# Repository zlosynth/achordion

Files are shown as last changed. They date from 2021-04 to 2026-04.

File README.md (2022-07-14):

# Achordion

Chord-crafting quantizing wavetable oscillator module for Eurorack.

<p align="center">
   Panel illustration
</p>

* Wavetable synthesis, 37 wavetables, smooth transitions
* Up to 18 simultaneous voices
* Sub-octaves, duplicated tones, and chords
* 4 styles of playing - single tone, chords, arpeggios, intervals
* Quantization to selected scale
* Any scale can be played with the white piano keys
* Two lines with independent 1V/oct inputs and audio outputs
* LEDs visualizing dialed parameters
* Based around Electro-Smith's [Daisy Patch SM](https://www.electro-smith.com/daisy/patch-sm) platform
* Programmed in Rust

Find more details about the module, including a feature overview video and a
user manual, on its [website](https://zlosynth.com/achordion).

# Firmware

If you wish to upgrade to a newer version of firmware, refer to the respective
[Release description](https://github.com/zlosynth/achordion/releases).

# Development

See [DEVELOPMENT.md](DEVELOPMENT.md) to find some basic commands to interact
with the project. To learn more, read the code. A good place to start would be
[eurorack/src/main.rs](eurorack/src/main.rs).

# License

Software of Achordion is distributed under the terms of the General Public
License version 3. See [LICENSE-SOFTWARE](LICENSE-SOFTWARE) for details.

Schematics and PCB layout are distributed under the terms of Creative Commons
BY-SA. See [LICENSE-HARDWARE](LICENSE-HARDWARE) for details. Parts of the
schematics are based on [Emilie Gillet's Mutable
Instruments](https://github.com/pichenettes/eurorack), kudos to her for making
them open.

The manual is distributed under the terms of Creative Commons BY-SA too. See
[LICENSE-MANUAL](LICENSE-MANUAL) for details.

# Changelog

Read the [CHANGELOG.md](CHANGELOG.md) to learn about changes introduced in each
release.

# Versioning

See [VERSIONING.md](VERSIONING.md) to find detailed information about versioning
of the project and compatability between its software and hardware.

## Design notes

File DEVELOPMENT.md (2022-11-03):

# Development

## Rust version

The firmware of this project fits really tight into the flash of Daisy Patch SM.
With anything newer than Rust 1.63.0, it just won't fit. Before working with
this project, please make sure to install needed Rust toolchains:

``` sh
rustup toolchain install 1.63.0-x86_64-unknown-linux-gnu
rustup target add thumbv7em-none-eabihf --toolchain 1.63.0
cargo +1.63.0 install cargo-binutils
rustup +1.63.0 component add llvm-tools-preview
```

## Cheat sheet

Run formatting, linter and unit tests:

``` sh
make
```

Check firmware size:

``` sh
cargo size -- -m
cargo size -- -A
cargo bloat --release -n 50
```

Analyze the call stack:

``` sh
cargo +nightly call-stack --bin achordion-eurorack > cg.dot
dot -Tsvg cg.dot > cg.svg
firefox cg.svg
```

Flash using ST-Link:

``` sh
cd eurorack
openocd &
cargo run --release
```

Flash using DFU:

``` sh
make flash
```

Benchmark:

``` sh
cargo bench --bench bench
```

Profiling:

``` sh
rm -f target/release/deps/bench-*
rm -f callgrind.out.*
RUSTFLAGS="-g" cargo bench --bench bench --no-run
BENCH=$(find target/release/deps -type f -executable -name 'bench-*')
TEST=instrument
valgrind \
    --tool=callgrind \
    --dump-instr=yes \
    --collect-jumps=yes \
    --simulate-cache=yes \
    ${BENCH} --bench --profile-time 10 ${TEST}
kcachegrind callgrind.out.*
```

Build the manual. Find built PDFs under `manual/user` and `manual/build`:

``` sh
make manual
```

And more under `hack/` and in the `Makefile`.

## Gerbers, BOM and CPL

I extensivelly use https://github.com/Bouni/kicad-jlcpcb-tools to deal with the
matters listed in the title, and to prepare project for manufacture.

## Bandlimiting algorithm

Bandlimiting is available with two different filtering algorithms - fast fourier
transform (FFT) removing high frequency bins and state variable filter (SVF).
While FFT provides crips clean and very sharp sound, SVF goes little harder on
filtering and leaves slighly more muted, but warmer sound. Preferred algorithm
can be selected through a feature in `Cargo.toml` of both Eurorack and Pure Data
modules.

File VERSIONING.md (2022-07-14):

# Versioning

The project adheres to [Semantic Versioning](https://semver.org/), this applies
to both hardware and software, where the same version is used for both.

## Compatibility

Software remains backwards compatible with the hardware. Although some
functionality may be missing when an older version of the board is used, the
module will remain functional.

This also follows Semantic Versioning, e.g. board released under version v1.1.0
will work fine with software of v1.3.0. When compatibility is broken, the major
version will be bumped, e.g. when software requires a new button on the board,
the major version will be bumped from v1.1.0 to v2.0.0 and the software will not
work anymore with older releases of the board.

Finally, releases with major version 0 may break any time.

## Releasing

All substantial changes are recorded in the [CHANGELOG.md](CHANGELOG.md).

To release a new version of the module, versions in all `Cargo.toml` files, PCB
layout, schematic and silkscreen on the board must be adjusted. The Unreleased
section of the changelog must be renamed to the relevant version. New version of
manuals and firmware must be uploaded as artifacts to the GitHub release.

This process is automated through `./hack/release.sh <new_version>`.

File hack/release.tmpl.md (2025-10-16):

## Changes

${CHANGES}

## Firmware

Achordion's firmware can be upgraded to obtain new features and bug-fixes. To do so, download the binary from attachments bellow, navigate to [Electro-Smith's web programmer](https://flash.daisy.audio/) and follow the guide to upload the binary throught the "File Upload" tab.

## Input quantization

By default, the input CV snaps to the closest note voltage. This works well with normal inputs or tones that are already quantized to the scale.

If you use a keyboard for CV source, consider trying the alternative firmare `achordion-firmware-x.y.z-white-key-quantization.bin` which maps white keys to all notes of the scale.

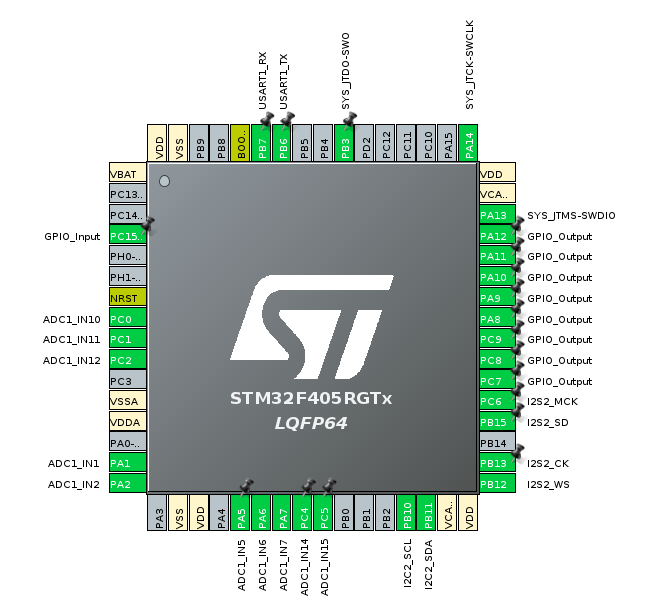
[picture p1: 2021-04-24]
eurorack/hardware/Screenshot from 2021-04-21 18-55-08.png

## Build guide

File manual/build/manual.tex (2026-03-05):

\documentclass[10pt,a4paper,twocolumn]{article}

\usepackage[T1]{fontenc} % extended font encoding
\usepackage{enumerate} % lists
\renewcommand{\familydefault}{\sfdefault} % sans-serif
\usepackage{microtype} % better text justification
\usepackage{graphicx} % allow including pictures
\usepackage{color} % colors for pictures
\usepackage{fancyhdr} % headers and footers
\usepackage{titling} % picture in the title
\usepackage{hyperref} % clickable links
\usepackage[left=2cm,right=2cm,top=3cm,bottom=3cm]{geometry} % wider and taller page

\pagenumbering{gobble} % hide page numbers
\setlength{\columnsep}{1cm} % space between columns
\setlength{\parskip}{\baselineskip} % paragraphs divided by empty lines
\setlength{\parindent}{0pt}

\pdfinfo{
   /Author (Zlosynth Instruments)
   /Title  (Achordion - Build Manual)
}

\pretitle{%
  \begin{center}
  \Huge
}
\posttitle{%
  \\
  \vspace{2cm}
  
  \end{center}
}

\begin{document}

\title{Achordion -- Build Manual}
\author{}
\date{}

\maketitle

\section{Overview}

You can always find the latest version of this build manual on \url{https://zlosynth.com/achordion-build-manual.pdf}.

This kit contains a printed circuit board (PCB) with all the surface mount device (SMD) parts already pre-soldered. The through-hole components are left to be assembled by you.

Pay attention to the orientation and position of all the parts. Desoldering them would be difficult and may break the module. Also, be careful not to touch the pre-soldered SMD parts with the soldering iron. Read through the whole manual first. Make sure you understand all the steps before you start soldering.

Electronic components are sensitive to static electricity. Before handling the PCB, ground yourself by touching a grounded metal object or use an anti-static wrist strap.

\newpage

\section{Tools required}

\begin{itemize}
  \item Soldering iron
  \item Masking tape
  \item Small flat head screwdriver
  \item Side-cutters
\end{itemize}

\newpage

\section{Bill of materials}

Start by unpacking all baggies into a bowl so you don't lose any components.

\begin{tabular}{@{}rl@{}}
  1 \texttimes & Front panel \\
  1 \texttimes & PCB (the black board) \\
  1 \texttimes & Daisy Patch Submodule (the yellow board) \\
  4 \texttimes & Potentiometer, M7 nut and washer \\
  1 \texttimes & Big knob \\
  3 \texttimes & Small knob \\
  7 \texttimes & 3.5mm jack socket, M6 nut and washer \\
  1 \texttimes & Tactile button \\
  8 \texttimes & Red LED \\
  1 \texttimes & Male connector 2\texttimes5 \\
  4 \texttimes & Female connector 2\texttimes5 \\
\end{tabular}

\begin{figure}[p]
  \centering
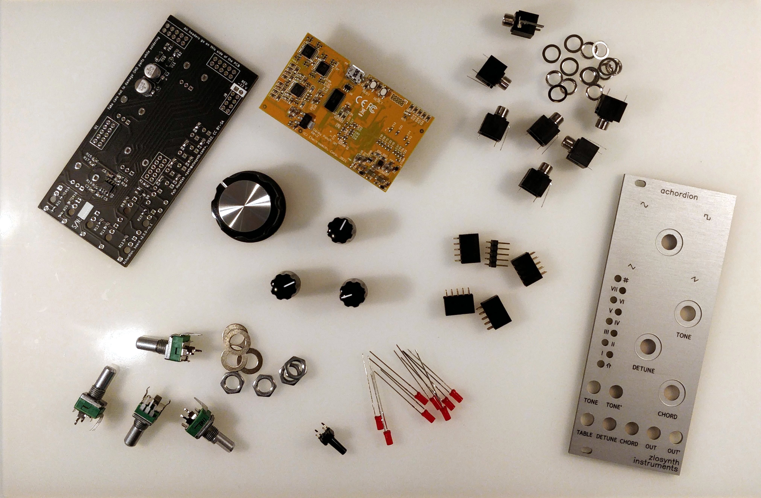
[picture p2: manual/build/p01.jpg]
  
  \caption{All the components laid out}
\end{figure}

\section{Daisy Patch Submodule}

The Daisy Patch Submodule is connected to the main PCB through a set of connectors.

\begin{enumerate}
  \item Mount the four female 2\texttimes5 connectors on the pins of the Daisy Patch Submodule. See figure \ref{daisy}. This will make it easier to align all the connectors properly.
  \item Plug the connectors of the submodule into the black PCB through footprints marked as ``SM''. Make sure to put them on the correct side of the PCB, where all four connectors are marked.
  \item Solder all the pins in.
  \item Once done, carefully detach Daisy Patch Submodule to prevent it from getting damaged while progressing with the build. It may be a little difficult. Pull each connector by a millimeter at a time.
\end{enumerate}

\begin{figure}[p]
  \centering
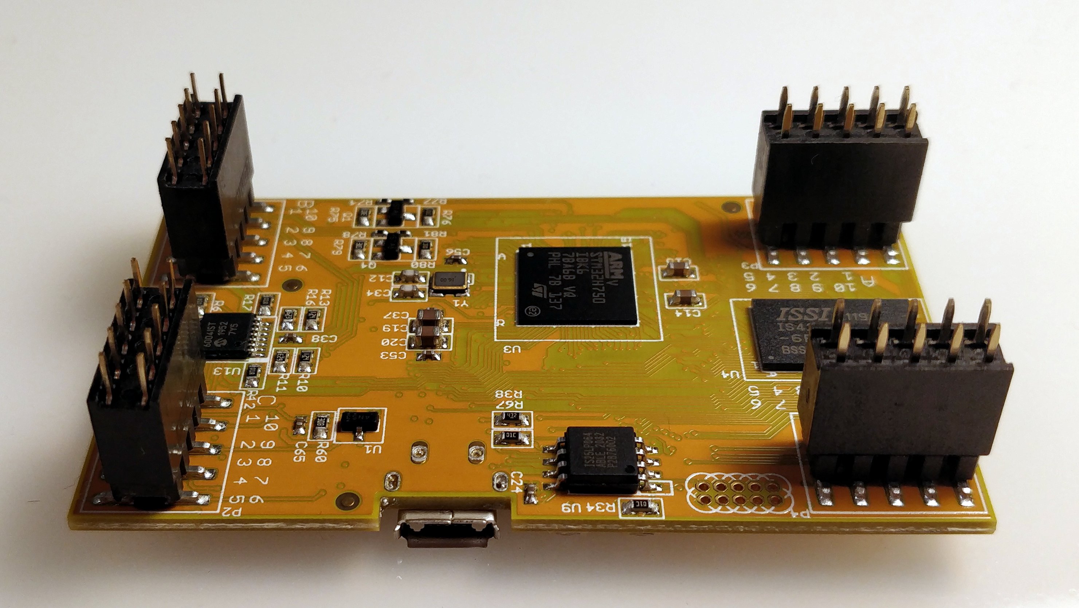
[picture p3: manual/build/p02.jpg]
  
  \caption{Connectors mounted on the submodule}
  \label{daisy}
\end{figure}

\section{Power}

The next step is to solder on the power connector.

\begin{enumerate}
  \item Take the male 2\texttimes5 connector and put the side with shorter legs through the footprint marked as ``Power''. Make sure to put it on the correct side of the PCB.
  \item Solder all the pins in. The result is illustrated in figure \ref{connectors}.
\end{enumerate}

\begin{figure}[p]
  \centering
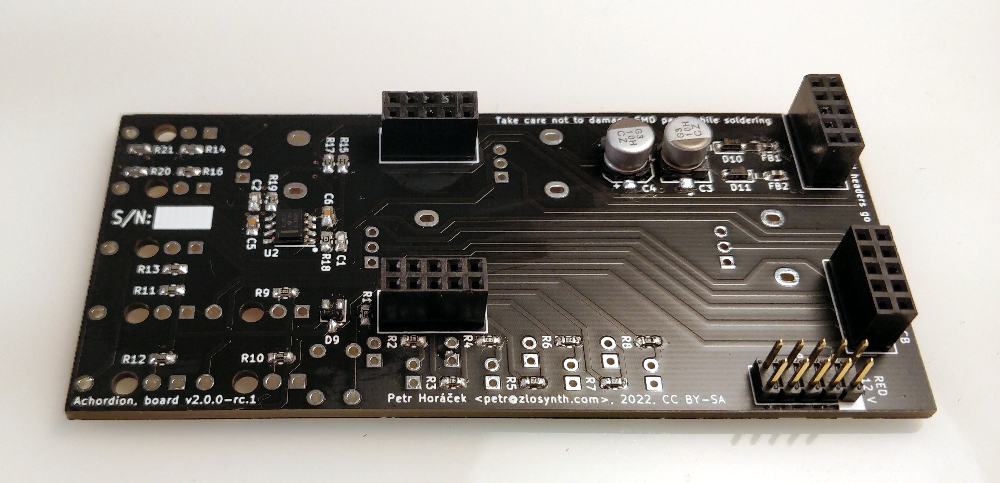
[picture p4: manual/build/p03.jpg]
  
  \caption{The power and submodule connectors}
  \label{connectors}
\end{figure}

\clearpage

\section{Front panel}

Now when all the internal parts are soldered, the next step would be to assemble parts sitting in the front panel.

\begin{enumerate}
  \item Snap in the button. Take care not to bend its leg. Don't push the button all the way to the PCB. See figure \ref{front components}.
  \item Place all potentiometers in the PCB. If the big legs are hard to snap in, flatten them with pliers first. Do not solder the legs yet.
  \item Put all jack sockets into the PCB.
  \item Put LEDs in place. The cathode (shorter leg) goes through the hole closer to the edge.
  \item Now when all parts are in, carefully put the front panel on them. Be patient aligning all parts so they fit through holes. The button may be a little problematic. If you see it not getting through, use tweezers to align its bottom part. Don't worry about the LEDs for now.
  \item Put washers on the pots and jacks. See figure \ref{washers}. Pot washers fit tightly into the panel, don't be afraid to push them in.
  \item Tighten all the potentiometers and jack sockets in place with their nuts. Take care not to scratch the panel. Plastic tools are prefered, and steel drivers should also serve well. If you only have pliers, put them in a thick plastic bag. Protect the panel!
  \item Solder in all the potentiometers and jacks.
  \item Use a masking tape on the portion of the panel with holes for LEDs, see figure \ref{masking}. Push the LEDs against the tape, even with the panel surface.
  \item Solder the LEDs. Then snap their legs off.
  \item Use tweezers to align the button. About 2 mm of the button should be sticking out of the panel. Test that the button can be easily clicked and returns to its resting position.
  \item Once the button is in a satisfying position, solder one of its legs, double-check it can be clicked and that it returns, and solder the remaining legs.
\end{enumerate}

\begin{figure}[p]
  \centering
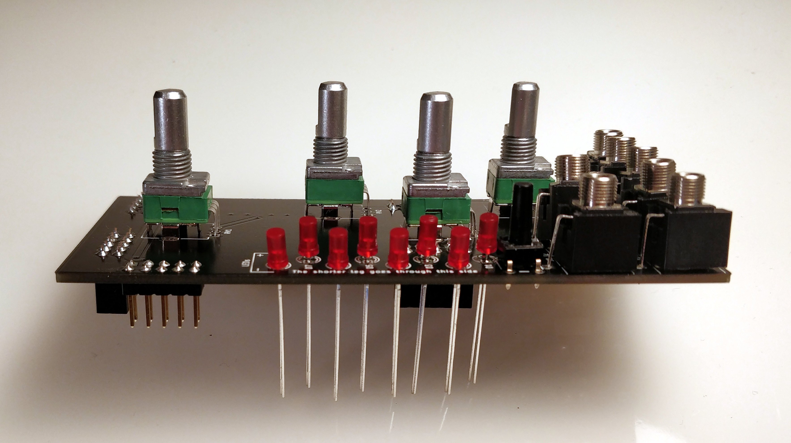
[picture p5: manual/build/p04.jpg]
  
  \caption{Side view with the front components in}
  \label{front components}
\end{figure}

\begin{figure}[p]
  \centering
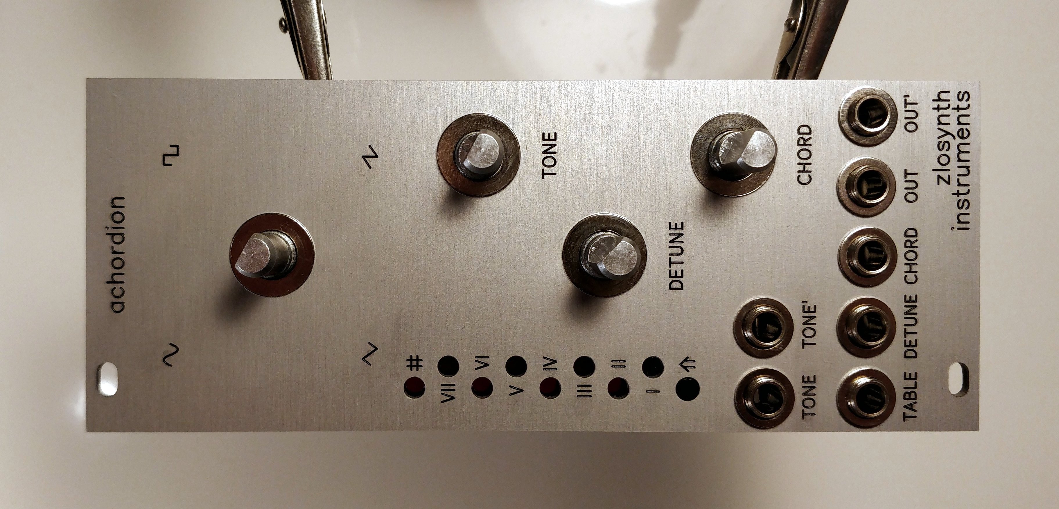
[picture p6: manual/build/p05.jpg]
  
  \caption{Pots and jacks with their washers on}
  \label{washers}
\end{figure}

\begin{figure}[p]
  \centering
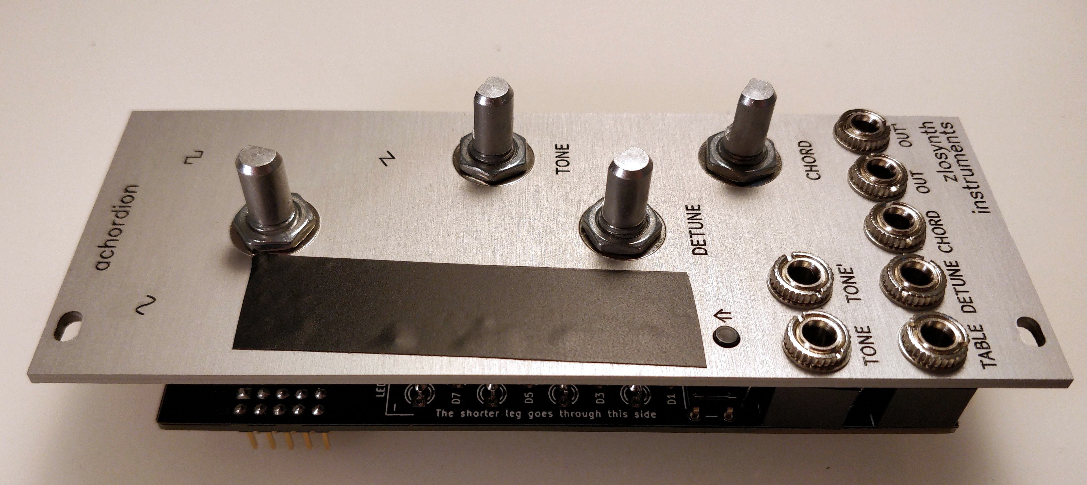
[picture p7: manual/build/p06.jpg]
  
  \caption{Taped LED holes}
  \label{masking}
\end{figure}

\clearpage

\section{Knobs}

You can now put knobs on the potentiometers.

\begin{enumerate}
  \item If the silver part of the big knob is protected with a sticky foil, peel it off.
  \item Put the big knob on the topmost potentiometer. Use a small flat screwdriver to tighten the screw of the pot. The screw should be pressing against the flat part of the shaft. Keep some distance between the knob and the panel.
  \item Put smaller black knobs on the remaining pots. Align them with the D-shaped shaft and press them in. You may need to pull them a little bit if you see they are scratching the nut.
\end{enumerate}

\begin{figure}[p]
  \centering
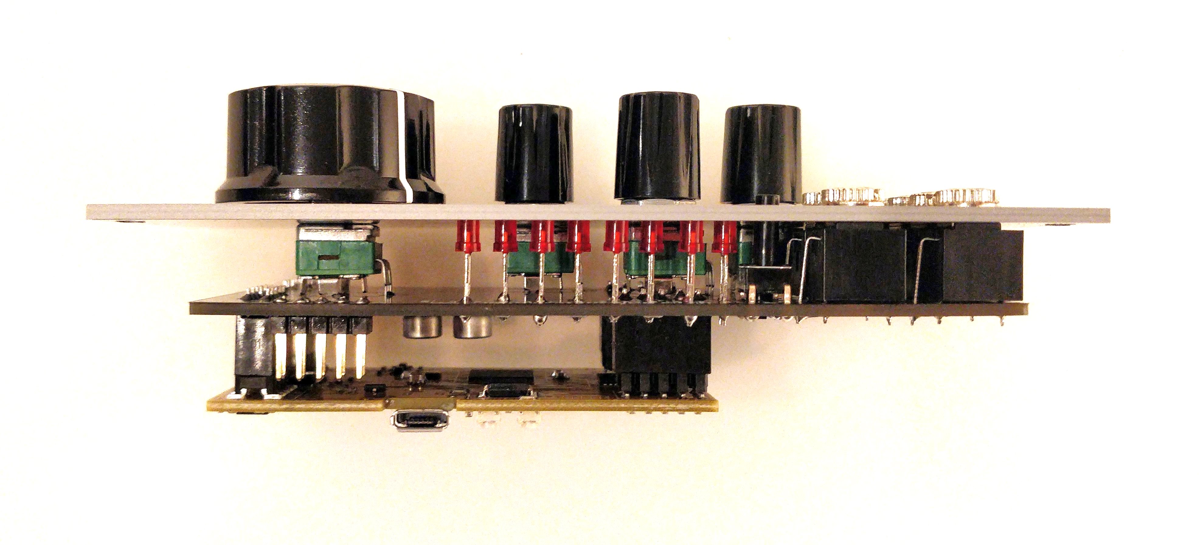
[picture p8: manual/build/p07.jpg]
  
  \caption{Side view of the assembled module}
\end{figure}

\section{Final assembly}

Connect the Daisy Patch Submodule to the main black PCB to complete the build.

\begin{figure}[p]
  \centering
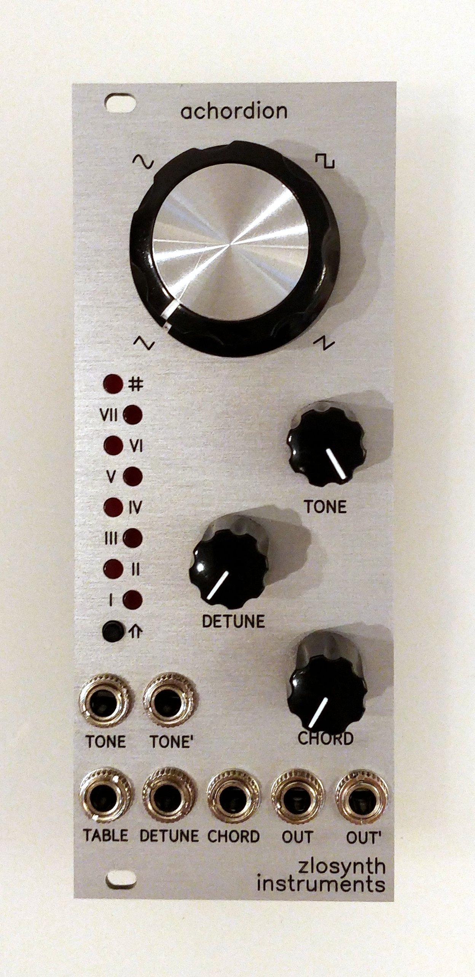
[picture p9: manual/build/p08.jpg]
  
  \caption{Front view of the assembled module}
\end{figure}

\section{Testing and inspection}

Before powering up the module, perform these checks to prevent damage:

\begin{itemize}
  \item Visually inspect all solder joints for missed connections, cold joints, and solder bridges.
  \item Always connect power with the system off. Verify the red stripe on the ribbon cable aligns with -12V on the PCB.
  \item If you can, test the module in an isolated case first to prevent damage to your entire Eurorack system if there are assembly errors.
\end{itemize}

\section{Congratulations}

The module is now complete. Have fun!

You can find the user manual on \url{https://zlosynth.com/achordion-user-manual.pdf}.

\end{document}

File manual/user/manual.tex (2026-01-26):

\documentclass[10pt,nofoldmark,nocombine]{leaflet} % digital leaflet format
% \documentclass[10pt,nofoldmark]{leaflet} % paper leaflet format

\usepackage[T1]{fontenc} % extended font encoding
\usepackage{enumerate} % lists
\renewcommand{\familydefault}{\sfdefault} % sans-serif
\usepackage{microtype} % better text justification
\usepackage{graphicx} % allow including pictures
\usepackage{color} % colors for pictures
\pagenumbering{gobble} % disable page numbering

\AddToBackground{1}{ % Background of a small page
  \put(0,0){\textcolor{black}{\rule{\paperwidth}{\paperheight}}}}

\newenvironment{packed_enumerate}{
\begin{enumerate}
  \setlength{\itemsep}{1pt}
  \setlength{\parskip}{0pt}
  \setlength{\parsep}{0pt}
}{\end{enumerate}}

\newenvironment{packed_enumerate_i}{
\begin{enumerate}[I]
  \setlength{\itemsep}{1pt}
  \setlength{\parskip}{0pt}
  \setlength{\parsep}{0pt}
}{\end{enumerate}}

\pdfinfo{
   /Author (Zlosynth Instruments)
   /Title  (Achordion - User Manual)
}

\begin{document}

\title{\textcolor{white}{MANUAL}}
\author{}
\date{}
\maketitle

\begin{center}
  
\end{center}

\newpage

\vspace{5mm}

Achordion allows you to do many things, but in essence, it is just a bunch of oscillators that never go out of tune or out of scale! Apart from playing anything between lush pads and hellish walls of sound, it enables you to easily jam with other musicians and explore characters of different scales. If you don't know any music theory, don't despair, the module will do all the harmony maths, and all left for you to do is to use your intuition. If you, on the other hand, do understand the basics of music theory, with this instrument, you can leverage it.

\section{Features}

This module is based on wavetable synthesis and contains a selection of 37 wavetables, offering smooth transitions between them. With up to 18 simultaneous voices, it allows enabling sub-octaves, duplicated tones or chords. Four modes of playing are available – single tone, selection of 18 standard chords (fifth, seventh and ninth), arpeggios, and intervals. All playing tones are quantized to a configurable scale. Two lines can be played at the same time, each controlled by an independent 1V/oct input. There are also two separate outputs, enabling to send each line to a different effect chain. Last but not least, a display consisting of 8 LEDs is used to make dialling of parameters easier.

\section{Installation}

Before installation, disconnect power from your case. While handling the module, avoid touching exposed components on the back of the PCB. Connect the power cable to your case power bus (2x5 connector on module side, 2x8 on bus side), ensuring the red stripe aligns with the -12V marking on both the module and power bus. Position the module on the rails and secure it with screws.

\section{Specs}

\begin{tabular}{@{}rl@{}}
  Width & 10 HP \\
  Depth & 28 mm \\
  Power & +12 V (85 mA), -12 V (7 mA) \\
  Input impedance & 100 kΩ \\
  CV inputs & 16-bit, 2 kHz \\
  Audio outputs & 24-bit, 48 kHz
\end{tabular}

\section{Controls, inputs and outputs}

On the left side, there is a column of LEDs (X) that visualize the currently selected parameter. The button below them (Y) accesses alternative parameters.

WAVETABLE (A) knob selects the wavetable. When the button is held down, this knob scrolls through banks.

TONE (B) knob selects the root note that should be playing. When the button is held down, this knob is used to select the scale's tonic.

DETUNE (C) knob controls the spread of secondary voices and the amount of detune. When the button is held down, this knob controls the scale mode.

CHORD (D) knob selects the chord or interval that should be playing. When the button is held down, this knob selects the mode in which chords are built.

CV inputs TONE (1) and TONE' (2) are used to control the root note playing on the main and the side line, respectively. When TONE is connected, the TONE knob controls octave offset. These inputs follow the 1V/oct standard, between -5 and +5 V.

CV inputs TABLE (3), DETUNE (4) and CHORD (5) control the same attributes as the knobs described above. The value set by the knob is added to the value set through the CV. All CV inputs span between -5 and +5~V.

Audio outputs OUT (6) and OUT' (7) play the main and the side line, respectively. When only one is connected, the outputs are mixed.

\section{Two Lines}

The module has two lines, the main line and the side line. The tone of these lines can be controlled independently while all the other attributes are shared.

The main line is controlled through the TONE knob and CV input. This line can play a chord, controlled through the CHORD knob and CV input.

The side line is controlled through the TONE' CV input and is playing only when a jack is connected. Unlike the main line, the side one is not playing chords.

\section{Wavetables}

There are 37 wavetables, divided into 4 banks:

\begin{packed_enumerate_i}
  \item Perfect -- classic waveforms: triangle, sine, square and saw. All of these are based on pure harmonics.
  \item Harsh -- full and distorted sounds. These can get very thick when played in rich chords.
  \item Soft -- cleaner sounds and bells.
  \item Sines -- the bottom half of this bank is a sequence of sine function multiplications that provide various sounds from clean to crazy noises. The upper half contains sums of sine functions. Sliding through them provides a low-pass filter effect.
\end{packed_enumerate_i}

The transitions between wavetables within a single bank are gradual and smooth, suitable for live modulation.

The bank can be selected by pressing the button while turning the WAVETABLE knob.

\section{Detune}

This parameter is set through the DETUNE knob and CV input. It controls the number of secondary voices per played note and their detune. The knob/CV input scrolls through four of these detune modes:

\begin{packed_enumerate_i}
  \item At first perfectly in tune, then moves each tone above or below its perfect pitch.
  \item The first factor of the chord is duplicated one octave lower. This is a classic sub-octave.
  \item Each tone in the chord is duplicated once with a unison. This produces a slight movement or vibrato effect, depending on the detune amount.
  \item Two sub-octaves per each factor. This can produce a very rich wall of sound and gets crazy with a lot of detune.
\end{packed_enumerate_i}

While moving through each mode, secondary voices are being gradually detuned. In lower detunes, the difference in frequency is very small and produces ``beats'' -- making the sound moving and warm. When it is pushed higher, it turns into a wild cacophony.

\section{Quantization}

To select the scale's root note, hold the button while turning the TONE knob. LEDs I through VII then symbolize notes of C major: C, D, ..., B. The \# LED signalizes that the note is sharp.

To select the scale's mode, hold the button while turning the DETUNE knob. LEDs I through VII then symbolize each of the modes. Selected mode affects the mood or character of the tune you are playing:

\begin{tabular}{@{}rl@{}@{}rl@{}}
  I & Ionian (major) \hspace{15mm} & V & Mixolydian  \\
  II & Dorian & VI & Aeolian (minor) \\
  III & Phrygian & VII & Locrian \\
  IV & Lydian & VIII & Harmonic minor \\
\end{tabular}

Quantization of TONE' can be switched off by tapping the DETUNE CV input with a jack while holding the button.

By default TONE and TONE' input CV snaps to the closest note. An alternative firmware can be installed to map white keyboard keys to the notes of any scale.

\section{Calibration}

While inputs TONE and TONE' follow the 1V/oct standard, they may not precisely match the connected CV source device. To calibrate each of these inputs, follow this procedure:

\begin{packed_enumerate}
  \item While holding the button, connect a jack to the input.
  \item The left column of LEDs should light up.
  \item Play note C on the CV source and press the button.
  \item Now, the right column of LEDs should light up.
  \item Play C one octave higher and press the button again.
\end{packed_enumerate}

\section{Chords}

This module allows playing chords of up to 5 factors, each affected by the detune.

To visualize selected chords, the LEDs display their factors. For example, if the selected chord is basic fifth, LEDs I, III and V light up to signalize that the first, third and fifth are playing. If this does not sound like anything to you, don't worry and just use your ears.

Furthermore, there are three different modes of playing chords. These can be accessed by holding the button while turning the CHORD knob:

\begin{packed_enumerate_i}
  \item Chords -- an assorted set of 19 chords. Starting with a single note, followed up with fifth, seventh, ninth and ninth inversions.
  \item Intervals -- not chords per se. In this mode, the root note is accompanied by another note of interval between minus two octaves to plus two octaves.
  \item Arpeggios -- four different chords that are incrementally built while the parameter is being increased. Starting with the root, adding second factor, third, ...
\end{packed_enumerate_i}

If the button is held while the chord CV is being plugged in, the input gets calibrated and can be then used in 1V/oct mode, with each chord assigned to a white key.

\section{Split Outputs}

There are two audio outputs in the module: OUT and OUT'. When only one of these outputs is connected, it gets mixed with the unconnected one. When both outputs are connected, each plays different voices. This allows to run through two different effect chains.

The content of these outputs depends on the playing lines. If the side line is playing, OUT plays the main line, controlled by TONE and OUT' is playing the side line, controlled by TONE'.

However, when the side line is not connected, OUT contains the root note of the main line, while OUT' contains the rest of the chord played by the main line.

\section{Reset}

Calibration settings and all secondary parameters (wavetable bank, scale tonic, scale mode, chord mode) are stored between restarts of the module. To reset their values, hold the button pressed while powering on the module.

\section{Configuration}

Some configuration options of the module can be adjusted:

\begin{packed_enumerate}
  \item Hold the button for 8 seconds.
  \item LEDs now signalize which options are enabled.
  \item Turn the WAVETABLE knob to adjust these options.
  \item Click the button to confirm the selection.
\end{packed_enumerate}

\begin{tabular}{@{}lll@{}}
  \textbf{LED} & \textbf{Option} \\
  VIII & \textit{reserved} \\
  VII  & \textit{reserved} \\
  VI   & \textit{reserved} \\
  V    & \textit{reserved} \\
  IV   & Tonic controlled by TONE' CV \\
  III  & Mode controlled by DETUNE CV \\
  II   & Modes ordered by brightness \\
  I    & Overdrive
\end{tabular}

\subsection{Tonic controlled by TONE' CV}

Scale's tonic can be controlled through the TONE' CV input, mapping to 1V/oct.

\subsection{Mode controlled by DETUNE CV}

Scale's mode can be controlled through the DETUNE CV input. The value set by the knob is added to the value set through the CV. The CV input spans between -5~and~+5~V.

\subsection{Modes ordered by brightness}

Modes can be reordered by their harmonic content, going from the brightest to the darkest.

\subsection{Overdrive}

Due to the headroom reserved for all 18 voices, default output levels are quite weak. To compensate for that, digital overdrive can be enabled. Note that this harms sound quality.

\section{Changelog}

\begin{tabular}{@{}rl@{}}
  v2.2 & The status LED blinks twice \\
       & Introduced configuration menu \\
       & Allow control of scale through CV \\
       & Add an option to order modes by brightness \\
       & Moved overdrive to the configuration menu \\
       & Added harmonic minor as the 8th mode \\
  v2.3 & The status LED blinks 3 times \\
       & First detune mode detunes all playing notes \\
  v2.4 & White key quantization was disabled \\
\end{tabular}

\section{Questions?}

\begin{center}
petr@zlosynth.com
\end{center}

\end{document}

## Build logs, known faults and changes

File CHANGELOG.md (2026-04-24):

# Changelog

All notable changes to this project will be documented in this file. See
[VERSIONING.md](VERSIONING.md) for more information about versioning and
backwards compatibility.

## Unreleased

* Use better footprints.
* Increase PCB edge clearance.

## 2.4.0

* Quantize TONE input 1V/oct CV to the closest note. The original white key
  quantization is now available as an alternative firmware.

## 2.3.0

* Introduce basic detune to the first detune section.
* Tune the output to match 440 Hz at A.
* Fix 1V/oct alignment of unquantized solo voice output.
* Pure Data externals were moved to a [dedicated project](https://github.com/zlosynth/automaton).
* Offer alternative firmware with white key quantization disabled.

## 2.2.1

* Split modal playing control to bind mode and scale CVs separately.
* Shift the range of TONE' by 2 octaves higher.
* Fix scaling of scale tonic CV to properly track 1V/oct.
* Persist tonic configuration between restarts.

## 2.2.0

* Blink the signal LED twice to signalize new version.
* Add harmonic minor mode.
* Introduce configuration menu.
* Allow remapping of CV inputs to control scale's tonic and mode.
* Enable overdrive through the configuration menu.
* Order of modes can be changed in the configuration menu.
* Extend the build manual with additional notes.
* Update pictures in the build manual to match version 2.

## 2.1.0

* Introduce togglable overdrive mode, compensating for big headroom.
* Add tooling holes to the PCB.
* Adjust V/oct response to reflect the new voltage range.
* Fix contents of each TONE output.

## 2.0.0

* Replace Daisy Seed with Daisy Patch Submodule, to assure CE requirements.
* Switch to 0805 footprints for easier hand-soldering.
* Change from 3 board to 2 board design to become skiff friendly.
* Remove debug pins due to lack of I/O.
* Prevent flash memory from getting worn out by utilizing its full range, saving
  only on change and increasing the backup interval.
* Blink the on-board LED every 2 seconds to indicate that the firmware is
  running.

## 1.3.1

* Fix english, change "unisono" to "unison".
* Disable line voice when its V/OCT input gets below zero.
* Fix a regression where the module would not fade in on boot.
* Document current requirements.

## 1.3.0

* Introduce documentation of the build process.
* Remove amplitude balancing on small chords. This causes weak signal output but
  guarantees stable loudness on continuous tones.
* Adjust solo and chord V/OCT tracking to react uniformly to input voltage.
* Avoid pops on chord changes by increasing the fade-in/out time of individual
  oscillators to 3 ms.

## 1.2.0

* Add mounting holes for distancing standoffs.
* Label boards and their sides to allow clear identification while building.
* Make it possible to disable quantization on the side line.
* Divide each octave V/OCT input to 7 almost equal sections.
* Document the depth of the module.
* Fully utilize the display while indicating the chord mode.
* Introduce V/OCT control of chords.
* Change CV range for chords to 0-10V.
* Improve the amplitude balance between low and high number of voices.
* Fix a bug where uninitialized voices would cause bit noise.
* Send solo output to SOLO' jack, as written in the documentation.
* Decrease the brightness of LEDs.

## 1.1.0

* The display now priorititizes what is being changed through pots over CV.
  Furthermore, one CV overtakes another only after the original source is idle.
* Fix calibration display. The lower octave is now signalized by LEDs on the
  left, higher on the right.
* Increase display sensitivity to CV, so it shows even small changes of input.
* If multiple CV inputs compete, the one that was controled through the pot most
  recently is picked.
* Prevent solo CV from bouncing between notes.
* Stabilize the display, so it does not blink while crossing large differences
  in V/OCT.
* Change the loading animation to go one LED at the time.
* Fix scale tonic control, so the pot does not wrap around when set to top.
* Resolve a bug where saved parameters sometimes failed to get restored.

## 1.0.0

* Convert PCB to two stacked layers for easier soldering.
* Change the panel layout.
* Expose debugging GPIO and UART pins.
* Wire compatibility version into the PCB.
* Document the module through a user manual.

## 0.16.0

* Allow using 3 voices in each chord degree.
* Use 2 sub-octave oscillators in the chord detune mode.
* Prevent phase lock by detuning solo if it collides with the chord.
* Prevent pop on change of detune by fading in/out the oscillators.
* Smoothly traverse wavetable changes between CV reconciles.
* Store bandlimited wavetables as f32 sequences to save on processing.
* Compensate amplitude of lower numbers of enabled oscillators.

## 0.15.0

* Speed up boot time of the module.
* Display progress of the boot on module's display.
* Exponentially fade in on boot.
* Increase the Note pot range to 6 octaves, extending in both directions.
* Make eurorack module louder.
* Replace vowel bank with sine multiple and sum sequences.
* Optimize booting code for size, to free up more space for wavetables.
* Make it possible to select between two bandlimiting algorithms.

## 0.14.0

* Introduce "style" setting to switch between different approaches to select
  harmonies. This also introduces alternative to chords where a simple interval
  +- 2 octaves is selected.
* Add a new play style which opens chords note by note. This could be used with
  ADSR connected to chord input to play more human-like.
* Add a new play mode which contains inversions of chords around the root.
* Increase the maximum number of chord degrees to 5 and populate the default
  chord style with some nineth chords.

## 0.13.0

* Add 4th voice to the instrument and allow its individual control through CV.
* List more accurate parts for the V/OCT CV input.
* Instead of pre-calculating bandlimited wavetables and storing them in flash,
  filter them during runtime initialization and store them in SRAM. This allows
  to fit more banks into eurorack and also to higher optimization.
* Reintroduce vowel wavetable bank into eurorack module.

## 0.12.0

* Align all quantization with white keys. All scales can be now played through
  white keys only, with black keys always quantizing to the previous white.
* Introduce CV calibration, allowing the V/OCT CV input to be calibrated
  precisely on any connected device.
* Allow reset of all stored parameters on boot by holding the button while
  powering on.
* Prevent jumps back and forth on borders between two discrete values of
  parameters.
* Scroll through notes via the pot lineary, instead of unequal jumps between
  tones and semitones.
* Increase detune phase on the display lineary.

## 0.11.0

* Remove CV buffering for faster response.
* Fixed a bug where settings backup to EEPROM was hogging the MCU and causing CV
  latency up to 100 ms. Now the CV latency should be around 2 ms.
* Increased control loop frequency to provide 0.5 ms latency.
* Simlified connected jack detection probe to reduce MCU usage.

## 0.10.0

* Update PCB with user labels for printing and easier soldering.
* Replace tantalum DC decoupling capacitors with aluminium.
* Use 10uF for DC decoupling capacitors.
* Scale modulation CV input range from -5 to +5 V.
* Scale V/OCT CV input range from 0 to +10 V.
* Add a script generating gerber and drill files.
* Add a script printing PDF with the schematic.
* Add a script printing PDF with assembly helper.
* Remove amplitude control.

## 0.9.0

* Remove component labels from the silkscreen.
* Add graphics to front and back of the PCB.
* Widen tracks on the PCB.
* Replace decoupling capacitor on DAC with LPF.
* Introduce ferrite beads to filter the power input.
* Major refactoring of the eurorack codebase, introducing new hardware
  abstractions.

## 0.8.1

* Fix dependency set on a daisy_bsp fork.

## 0.8.0

* Persist dialed settings between restarts.

## 0.7.0

* Visualize changes in settings on the display, both from pots and CV.
* Allow to offset Note CV to negative to compensate for high voltage input.
* Fix equilibrium of wavetables with depth of 16 bits.

## 0.6.0

* Added tooling supporting generation of wavetables from raw audio.
* Lowered LPF on wavetables to make the lower end thicker.
* Use floats for audio buffers instead of u16.
* Remove pulse wavetable bank.
* Add a bank compiled of FM, distorted and sampled wavetables.
* Add a bank compiled of soft wavetables.
* Add a bank of vocal wavetables.

## 0.5.0

* Allow control of wavetable bank through Wavetable pot while holding the
  button.
* Allow control of scale root through Note pot while holding the button. This
  value will be combined with the Tonic CV in case it is connected.
* Allow control of scale mode through Chord pot while holding the button. This
  value will be combined with the Mode CV in case it is connected.
* Remove support for 4 degrees of chords. It draws too much resources.

## 0.4.0

* Allowed control of all parameters through CV:
  - Root note, adhering to V/OCT. When connected, Note potentiometer controls
    octave offset.
  - Wavetable position. When connected, Wavetable potentiometer controls the
    offset.
  - Chord. When connected, Chord potentiometer controls the offset.
  - Detune. When connected, Detune potentiometer controls the offset.
  - Scale mode.
  - Scale root note, adhering to V/OCT.
* Fixed the bug where root and chord went to both channels.
* Introduced fade in when the module is powered on.
* Fixed an issue where full detune setting would disable detune.

## 0.3.0

* Detune sections now respond logarithmically, this allows for finer control in
  lower values.
* Added pulse waveforms of variable width.
* Support multiple wavetable banks.
* Label button and probe pins on the PCB.
* Switch to Daisy Seed, STM32H7.

## 0.2.0

* Finally starting using Semantic Versioning.
* Compensate perceived amplitudes, making sure that combination of less
  oscillators sound as loud as many.
* Added support for silenced chord degrees, allowing for subset of voices to
  sound and build smaller chords/intervals.
* Added support for chord degrees spanning multiple upwards octaves.
* Added support for inverted chords.
* Added support for seventh chords.
* Defined versioning and compatibility policies.

## 7123cbb, revision 3

* Increased size of pads on the PCB for easier hand soldering.

## 27707a5, revision 2

* Converted the board into 2-layer design.
* Replacing 7-segment display with LEDs.
* Added CV probing to the PCB, allowing to detect connected jacks.
* Mixing both output channels when only one jack is plugged in.
* Added labels to PCB silkscreen.
* Spaced out jack sockets on the PCB.
* Adjusted all the CV ranges.
* Introduced Pure Data External to allow for easier testing.
* Quantizing note to diatonic scale.
* Wavetable control.
* Chord control.
* Removed control over MIDI.
* Added detune control and suboscillators.
* Improved reading of potentiometer values with buffering.

## cb3808f, revision 1

* Introduced panel sketch.
* PCB designed based around Daisy Seed.
* 4 basic waveforms.
* Quantizing notes to selected scale.
* Chord, scale mode, and tone controlled via MIDI over USB.

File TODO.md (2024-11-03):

# TODO

- [ ] Make even quantization of input the default. Note in the docs that if white key quantization is not tracking accurately, alternative firmware is available.
- [ ] Switch to bootloader, to allow bigger firmware size. Adapt the build scripts, update the DEVEL and release note guides.
- [ ] Switch to the scale library of Arplus.
- [ ] Implement controlled mode, with scales being set by Arplus.

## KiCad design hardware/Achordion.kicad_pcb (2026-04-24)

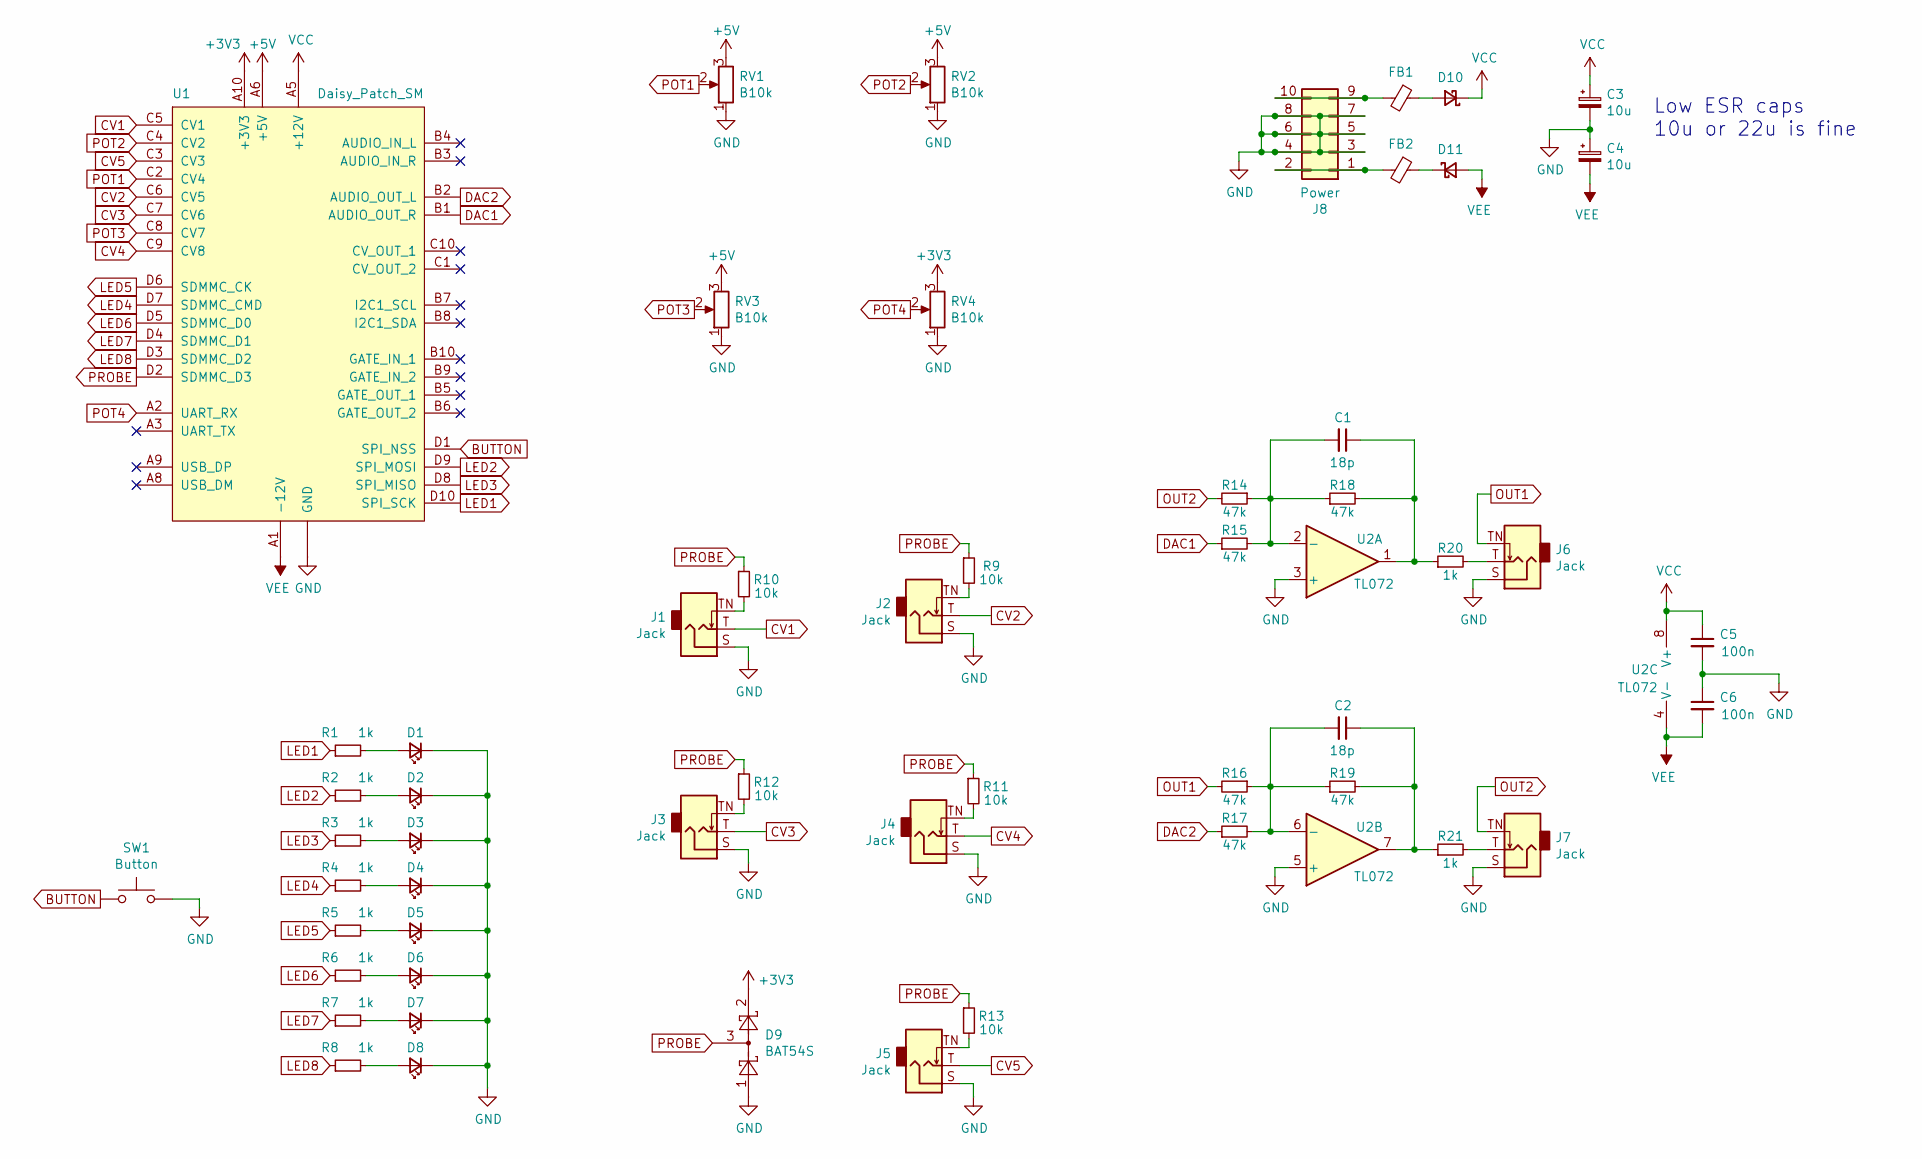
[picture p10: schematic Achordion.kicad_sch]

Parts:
C1, C2: 18p; C_0805_2012Metric_Pad1.18x1.45mm_HandSolder; Mfr Part Number CL10C180JB81PNC; LCSC C1647
C3, C4: 10u; CP_Elec_5x5.8; Mfr Part Number T491B226M016AT; LCSC C122226
C5, C6: 100n; C_0805_2012Metric_Pad1.18x1.45mm_HandSolder; Mfr Part Number CL10F104ZO8NNNC; LCSC C14663
D1, D2, D3, D4, D5, D6, D7, D8: LED; LED_D3.0mm; Mfr Part Number WP710A10SRD/D
D9: BAT54S; SOT-23_Handsoldering; Mfr Part Number BAT54S,215
D10, D11: Schottky; D_SOD-123; Mfr Part Number STPS0540ZY; LCSC C8598
FB1, FB2: FB; L_0805_2012Metric_Pad1.05x1.20mm_HandSolder
J1, J2, J3, J4, J5, J6, J7: Jack; Jack_3.5mm_QingPu_WQP-PJ398SM_Vertical_CircularHoles
J8: Power; Power_Connector_Connfly; Mfr Part Number 87914-1016
R1, R2, R3, R4, R5, R6, R7, R8: 1k; R_0805_2012Metric_Pad1.20x1.40mm_HandSolder; Mfr Part Number CR0603-FX-3650ELF; LCSC C23032
R9, R10, R11, R12, R13: 10k; R_0805_2012Metric_Pad1.20x1.40mm_HandSolder; Mfr Part Number CR0603-FX-1002ELF; LCSC C25744
R14, R16, R18, R19: 47k; R_0805_2012Metric_Pad1.20x1.40mm_HandSolder; Mfr Part Number CR0603-FX-4702ELF; LCSC C25819
R15, R17: 47k; R_0805_2012Metric_Pad1.20x1.40mm_HandSolder; Mfr Part Number CR0603-JW-682ELF; LCSC C23212
R20, R21: 1k; R_0805_2012Metric_Pad1.20x1.40mm_HandSolder; Mfr Part Number CR0603-FX-1001ELF; LCSC C21190
RV1, RV2, RV3, RV4: B10k; Potentiometer_Alpha; Mfr Part Number RK09L1140A66
SW1: Button; SW_PUSH_6mm; Mfr Part Number SKHHDTA010
U1: Daisy_Patch_SM
U2: TL072; SOIC-8_3.9x4.9mm_P1.27mm; Mfr Part Number TL072CD; LCSC C163525

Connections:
+3V3: D9.2, RV4.3, U1.A10 (+3V3)
+5V: RV1.3, RV2.3, RV3.3, U1.A6 (+5V)
BUTTON: SW1.1, U1.D1 (SPI_NSS)
CV1: J1.T, U1.C5 (CV1)
CV2: J2.T, U1.C6 (CV5)
CV3: J3.T, U1.C7 (CV6)
CV4: J4.T, U1.C9 (CV8)
CV5: J5.T, U1.C3 (CV3)
DAC1: R15.1, U1.B1 (AUDIO_OUT_R)
DAC2: R17.1, U1.B2 (AUDIO_OUT_L)
GND: C3.2, C4.1, C5.2, C6.1, D1.1 (K), D2.1 (K), D3.1 (K), D4.1 (K), D5.1 (K), D6.1 (K), D7.1 (K), D8.1 (K), D9.1, J1.S, J2.S, J3.S, J4.S, J5.S, J6.S, J7.S, J8.3, J8.4, J8.5, J8.6, J8.7, J8.8, RV1.1, RV2.1, RV3.1, RV4.1, SW1.2, U1.A4 (GND), U1.A7 (GND), U2.3 (+), U2.5 (+)
LED1: R1.1, U1.D10 (SPI_SCK)
LED2: R2.1, U1.D9 (SPI_MOSI)
LED3: R3.1, U1.D8 (SPI_MISO)
LED4: R4.1, U1.D7 (SDMMC_CMD)
LED5: R5.1, U1.D6 (SDMMC_CK)
LED6: R6.1, U1.D5 (SDMMC_D0)
LED7: R7.1, U1.D4 (SDMMC_D1)
LED8: R8.1, U1.D3 (SDMMC_D2)
unnamed: C1.1, R18.2, R20.1, U2.1
unnamed: C2.1, R19.2, R21.1, U2.7
unnamed: D1.2 (A), R1.2
unnamed: D2.2 (A), R2.2
unnamed: D3.2 (A), R3.2
unnamed: D4.2 (A), R4.2
unnamed: D5.2 (A), R5.2
unnamed: D6.2 (A), R6.2
unnamed: D7.2 (A), R7.2
unnamed: D8.2 (A), R8.2
unnamed: D10.2 (A), FB1.1
unnamed: D11.1 (K), FB2.1
unnamed: J1.TN, R10.2
unnamed: J2.TN, R9.2
unnamed: J3.TN, R12.2
unnamed: J4.TN, R11.2
unnamed: J5.TN, R13.2
unnamed: J6.T, R20.2
unnamed: J7.T, R21.2
unnamed: FB2.2, J8.1, J8.2
unnamed: FB1.2, J8.9, J8.10
unnamed: C1.2, R14.1, R15.2, R18.1, U2.2 (-)
unnamed: C2.2, R16.1, R17.2, R19.1, U2.6 (-)
OUT1: J6.TN, R16.2
OUT2: J7.TN, R14.2
POT1: RV1.2, U1.C2 (CV4)
POT2: RV2.2, U1.C4 (CV2)
POT3: RV3.2, U1.C8 (CV7)
POT4: RV4.2, U1.A2 (UART_RX)
PROBE: D9.3, R9.1, R10.1, R11.1, R12.1, R13.1, U1.D2 (SDMMC_D3)
VCC: C3.1, C5.1, D10.1 (K), U1.A5 (+12V), U2.8 (V+)
VEE: C4.2, C6.2, D11.2 (A), U1.A1 (-12V), U2.4 (V-)

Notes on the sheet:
Low ESR caps 10u or 22u is fine

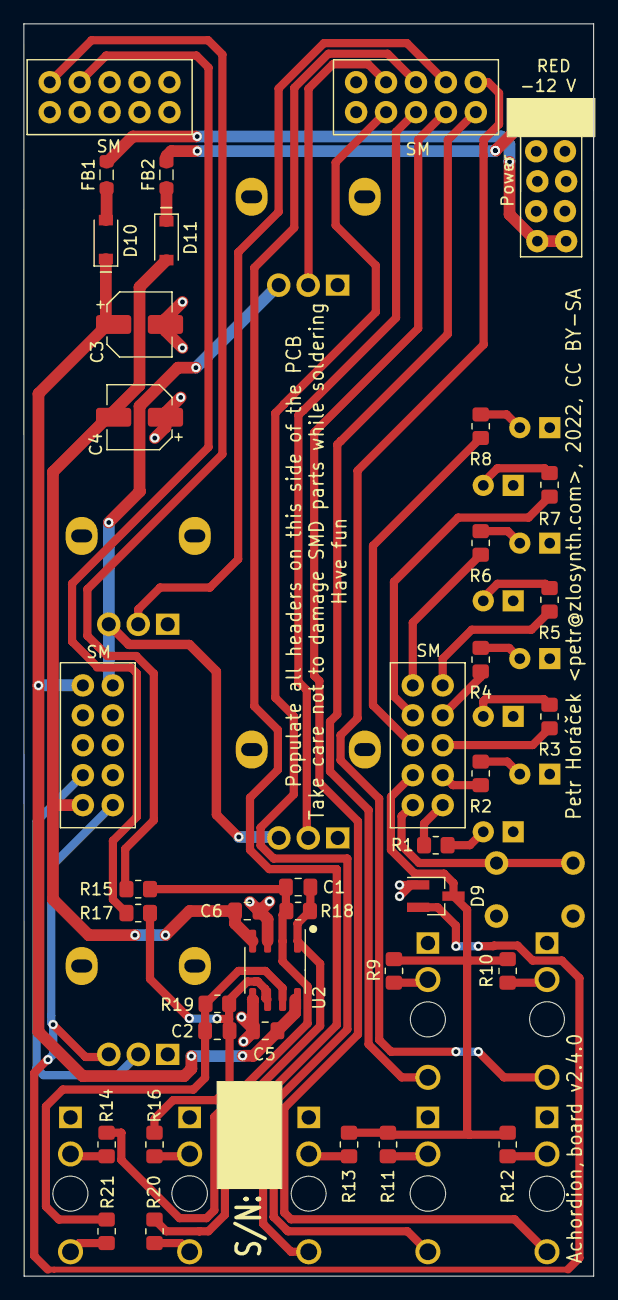
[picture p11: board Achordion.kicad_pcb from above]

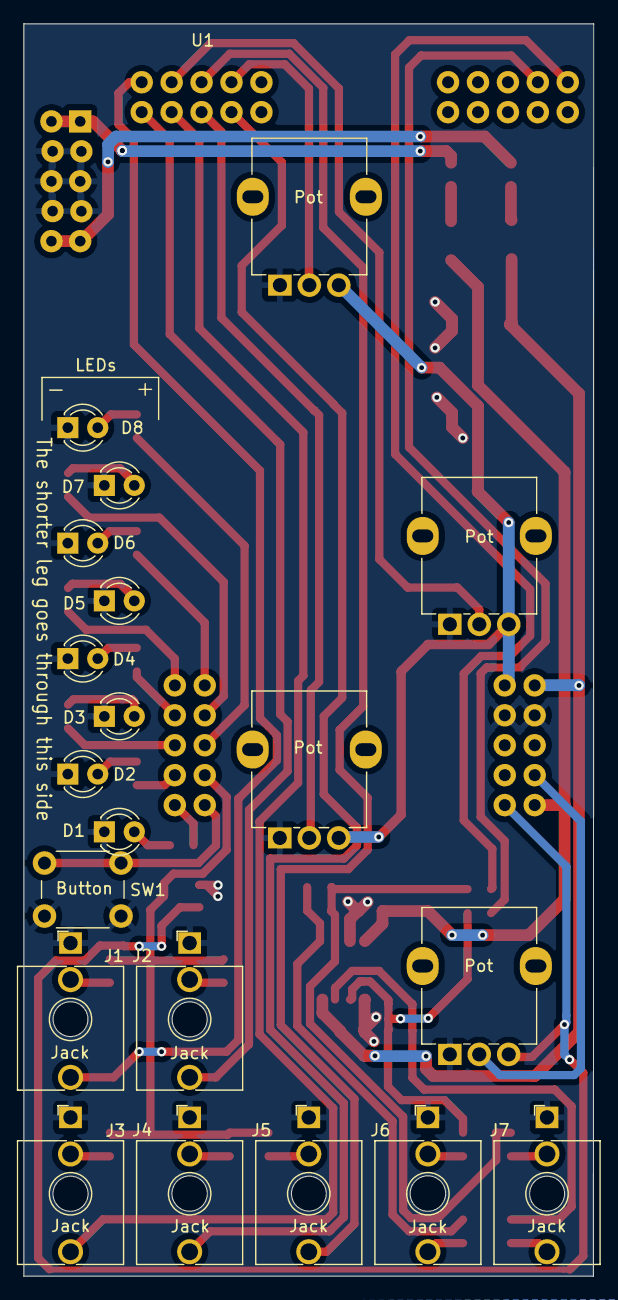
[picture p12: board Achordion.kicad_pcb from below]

Board: 2 copper layers, 48.4 x 106.3 mm, 55 parts (21 on the bottom side), 51 nets.

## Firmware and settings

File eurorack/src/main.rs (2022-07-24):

#![no_std]
#![no_main]
#![allow(unknown_lints)]
#![allow(clippy::inconsistent_struct_constructor)]
#![allow(clippy::new_without_default)]
#![allow(clippy::manual_map)]

mod bank;
mod controls;
mod display;
mod input_activity;
mod storage;
mod system;

#[macro_use]
mod profiling;

use panic_halt as _;

#[allow(unused_imports)]
use micromath::F32Ext;

use rtic::app;
use rtic::cyccnt::Instant;
use rtic::cyccnt::U32Ext as _;

use achordion_lib::display::{self as display_lib, Action as DisplayAction, CalibrationPhase};
use achordion_lib::instrument::Instrument;
use achordion_lib::store::Parameters;

use crate::bank::WAVETABLE_BANKS;
use crate::controls::{Controls, ControlsConfig};
use crate::display::{Display, DisplayConfig};
use crate::input_activity::InputActivity;
use crate::storage::Storage;
use crate::system::audio::{Audio, BLOCK_LENGTH, SAMPLE_RATE};
use crate::system::led_user::{Led, LedUser};
use crate::system::System;

pub const SECOND: u32 = 480_000_000;
const CV_PERIOD: u32 = SECOND / 2000;

const BLINKS: u8 = 2;

const BACKUP_COUNTDOWN_LENGTH: u8 = 60;
const BACKUP_COUNTDOWN_SLEEP: u32 = SECOND;

#[app(device = stm32h7xx_hal::pac, peripherals = true, monotonic = rtic::cyccnt::CYCCNT)]
const APP: () = {
    struct Resources {
        controls: Controls,
        display: Display,
        storage: Storage,
        led_user: LedUser,
        input_activity: InputActivity,
        audio: Audio,
        instrument: Option<Instrument<'static>>,
        lastly_stored_parameters: Parameters,
    }

    /// Initialize all the peripherals.
    #[init(spawn = [initialize])]
    fn init(cx: init::Context) -> init::LateResources {
        let system = System::init(cx.core, cx.device);

        let mut storage = Storage::new(system.flash);

        let parameters = if system.button.active_no_filter() {
            let parameters = Parameters::default();
            while system.button.active_no_filter() {}
            parameters
        } else {
            storage.load_parameters()
        };

        let controls = Controls::new(
            ControlsConfig {
                adc1: system.adc1,
                adc2: system.adc2,
                alt_button: system.button,
                pot_wavetable: system.pots.pot1,
                pot_note: system.pots.pot2,
                pot_detune: system.pots.pot3,
                pot_chord: system.pots.pot4,
                cv_voct: system.cvs.cv1,
                cv_solo: system.cvs.cv2,
                cv_wavetable: system.cvs.cv3,
                cv_detune: system.cvs.cv4,
                cv_chord: system.cvs.cv5,
                cv_probe: system.cvs.cv_probe,
            },
            parameters,
        );

        let display = Display::new(DisplayConfig {
            led1: system.leds.led1,
            led2: system.leds.led2,
            led3: system.leds.led3,
            led4: system.leds.led4,
            led5: system.leds.led5,
            led6: system.leds.led6,
            led7: system.leds.led7,
            led_sharp: system.leds.led8,
        });

        let mut audio = system.audio;
        audio.spawn();

        cx.spawn.initialize().unwrap();

        init::LateResources {
            controls,
            display,
            audio,
            storage,
            led_user: system.led_user,
            instrument: None,
            input_activity: InputActivity::new(),
            lastly_stored_parameters: parameters,
        }
    }

    #[task(schedule = [fade_in, reconcile_controls], spawn = [backup_countdown, blink], resources = [display, instrument], priority = 2)]
    fn initialize(mut cx: initialize::Context) {
        let display = cx.resources.display;
        bank::setup(display);

        let mut instrument = Instrument::new(
            unsafe { &WAVETABLE_BANKS.as_ref().unwrap()[..] },
            SAMPLE_RATE,
        );
        instrument.set_amplitude(0.0);

        cx.resources
            .instrument
            .lock(|resource| *resource = Some(instrument));

        cx.schedule
            .reconcile_controls(Instant::now() + CV_PERIOD.cycles())
            .unwrap();
        cx.schedule
            .fade_in(Instant::now() + (SECOND / 10).cycles())
            .unwrap();
        cx.spawn.backup_countdown(BACKUP_COUNTDOWN_LENGTH).unwrap();
        cx.spawn.blink(true, BLINKS).unwrap();
    }

    #[task(binds = DMA1_STR1, priority = 3, resources = [audio, instrument])]
    fn dsp(cx: dsp::Context) {
        let audio = cx.resources.audio;

        let mut buffer_solo = [0.0; BLOCK_LENGTH];
        let mut buffer_chord = [0.0; BLOCK_LENGTH];

        if let Some(instrument) = cx.resources.instrument {
            instrument.populate(&mut buffer_solo, &mut buffer_chord);
        }

        audio.update_buffer(|buffer| {
            buffer.iter_mut().enumerate().for_each(|(i, x)| {
                *x = (buffer_chord[i], buffer_solo[i]);
            })
        });
    }

    #[task(schedule = [fade_in], resources = [instrument], priority = 2)]
    fn fade_in(mut cx: fade_in::Context) {
        let mut amplitude = 0.0;

        cx.resources.instrument.lock(|instrument| {
            let instrument = instrument.as_mut().unwrap();
            amplitude = if instrument.amplitude() < 0.00005 {
                0.0001
            } else {
                instrument.amplitude() * 1.1
            };
            instrument.set_amplitude(amplitude.min(1.0));
        });

        if amplitude < 1.0 {
            cx.schedule
                .fade_in(Instant::now() + 6_000_000.cycles())
                .unwrap();
        }
    }

    #[task(schedule = [reconcile_controls], resources = [controls, display, instrument, input_activity], priority = 2)]
    fn reconcile_controls(mut cx: reconcile_controls::Context) {
        let activity = cx.resources.input_activity;
        let controls = cx.resources.controls;
        let display = cx.resources.display;

        controls.update();

        let mut calibration_action = None;
        let mut configuration_action = None;
        let mut any_actions = None;
        let mut pot_actions = None;
        let mut chord_degrees = None;

        cx.resources.instrument.lock(|instrument| {
            let instrument = instrument.as_mut().unwrap();
            calibration_action = Some(reconcile_calibration(controls));
            configuration_action = Some(reconcile_configuration(controls));
            any_actions = Some(reconcile_all_changes(controls, instrument));
            pot_actions = Some(reconcile_pot_activity(controls, instrument));
            chord_degrees = Some(instrument.chord_degrees());
        });

        if let Some(display_action) = activity.reconcile(
            calibration_action.unwrap(),
            configuration_action.unwrap(),
            pot_actions.unwrap(),
            any_actions.unwrap(),
            DisplayAction::SetChord(chord_degrees.unwrap()),
        ) {
            display.set(display_lib::reduce(display_action));
        };

        cx.schedule
            .reconcile_controls(Instant::now() + CV_PERIOD.cycles())
            .unwrap();
    }

    #[task(schedule = [backup_countdown], spawn = [backup_collector], priority = 2)]
    fn backup_countdown(cx: backup_countdown::Context, countdown: u8) {
        fn launch_backup_collector(cx: backup_countdown::Context) {
            cx.spawn.backup_collector().ok().unwrap();
        }

        fn tick_countdown(cx: backup_countdown::Context, countdown: u8) {
            cx.schedule
                .backup_countdown(Instant::now() + BACKUP_COUNTDOWN_SLEEP.cycles(), countdown)
                .unwrap();
        }

        if countdown > 1 {
            tick_countdown(cx, countdown - 1);
        } else {
            launch_backup_collector(cx);
        }
    }

    #[task(spawn = [backup_executor], resources = [controls], priority = 2)]
    fn backup_collector(cx: backup_collector::Context) {
        fn launch_backup_executor(cx: backup_collector::Context, parameters: Parameters) {
            cx.spawn.backup_executor(parameters).ok().unwrap();
        }

        let parameters = cx.resources.controls.parameters();
        launch_backup_executor(cx, parameters);
    }

    #[task(schedule = [backup_countdown], resources = [storage, lastly_stored_parameters])]
    fn backup_executor(mut cx: backup_executor::Context, parameters: Parameters) {
        fn start_countdown(cx: backup_executor::Context) {
            cx.schedule
                .backup_countdown(
                    Instant::now() + BACKUP_COUNTDOWN_SLEEP.cycles(),
                    BACKUP_COUNTDOWN_LENGTH,
                )
                .unwrap();
        }

        let lastly_stored_parameters = &mut cx.resources.lastly_stored_parameters;

        if parameters.close_to(lastly_stored_parameters) {
            start_countdown(cx);
        } else {
            **lastly_stored_parameters = parameters;

            let storage = &mut cx.resources.storage;
            storage.save_parameters(parameters);

            start_countdown(cx);
        }
    }

    #[task(schedule = [blink], resources = [led_user])]
    fn blink(cx: blink::Context, on: bool, blinks: u8) {
        const TIME_ON: u32 = SECOND / 5;
        const TIME_OFF_SHORT: u32 = SECOND / 5;
        const TIME_OFF_LONG: u32 = 2 * SECOND;

        if on {
            cx.resources.led_user.on();
            cx.schedule
                .blink(Instant::now() + TIME_ON.cycles(), false, blinks)
                .unwrap();
        } else {
            cx.resources.led_user.off();
            if blinks > 1 {
                cx.schedule
                    .blink(Instant::now() + TIME_OFF_SHORT.cycles(), true, blinks - 1)
                    .unwrap();
            } else {
                cx.schedule
                    .blink(Instant::now() + TIME_OFF_LONG.cycles(), true, BLINKS)
                    .unwrap();
            }
        }
    }

    extern "C" {
        fn EXTI0();
        fn EXTI1();
    }
};

fn reconcile_calibration(controls: &mut Controls) -> Option<DisplayAction> {
    if controls.calibration_waiting_low() {
        Some(DisplayAction::SetCalibration(CalibrationPhase::WaitingLow))
    } else if controls.calibration_waiting_high() {
        Some(DisplayAction::SetCalibration(CalibrationPhase::WaitingHigh))
    } else if controls.calibration_succeeded() {
        Some(DisplayAction::SetCalibration(CalibrationPhase::Succeeded))
    } else if controls.calibration_failed() {
        Some(DisplayAction::SetCalibration(CalibrationPhase::Failed))
    } else {
        None
    }
}

fn reconcile_configuration(controls: &mut Controls) -> Option<DisplayAction> {
    if controls.config_open() {
        Some(DisplayAction::SetConfiguration(controls.config().into()))
    } else {
        None
    }
}

fn reconcile_all_changes(
    controls: &mut Controls,
    instrument: &mut Instrument,
) -> [Option<DisplayAction>; 9] {
    let new_chord_root_degree = if controls.note_from_pot() {
        instrument.set_chord_root_linear(controls.note())
    } else {
        instrument.set_chord_root_voct(controls.note())
    };
    let chord_root_action = if let Some(new_chord_root_degree) = new_chord_root_degree {
        Some(DisplayAction::SetChordRootDegree(new_chord_root_degree))
    } else {
        None
    };

    let new_degrees = instrument.set_chord_degrees(controls.chord());
    let degrees_action = if let Some(new_degrees) = new_degrees {
        Some(DisplayAction::SetChord(new_degrees))
    } else {
        None
    };

    instrument.set_chord_quantization(controls.chord_quantization());

    let new_solo = instrument.set_solo_voct(controls.solo());
    let solo_action = if let Some(new_solo) = new_solo {
        Some(DisplayAction::SetSolo(new_solo))
    } else {
        None
    };

    instrument.set_solo_quantization(controls.solo_quantization());

    let new_scale_root = instrument.set_scale_root_voct(controls.scale_root());
    let scale_root_action = if let Some(new_scale_root) = new_scale_root {
        Some(DisplayAction::SetScaleRoot(new_scale_root))
    } else {
        None
    };

    let new_scale_mode = instrument.set_scale_mode(
        controls.scale_mode(),
        controls.modes_ordered_by_brightness(),
    );
    let scale_mode_action = if let Some(new_scale_mode) = new_scale_mode {
        Some(DisplayAction::SetScaleMode(new_scale_mode))
    } else {
        None
    };

    let new_wavetable_bank = instrument.set_wavetable_bank(controls.wavetable_bank());
    let wavetable_bank_action = if let Some(new_wavetable_bank) = new_wavetable_bank {
        Some(DisplayAction::SetWavetableBank(new_wavetable_bank))
    } else {
        None
    };

    let new_wavetable = instrument.set_wavetable(controls.wavetable());
    let wavetable_action = if let Some(new_wavetable) = new_wavetable {
        Some(DisplayAction::SetWavetable(new_wavetable))
    } else {
        None
    };

    let new_style = instrument.set_style(controls.style());
    let style_action = if let Some(new_style) = new_style {
        Some(DisplayAction::SetStyle(new_style))
    } else {
        None
    };

    let new_detune = instrument.set_detune(controls.detune());
    let detune_action = if let Some((new_detune_index, new_detune_phase)) = new_detune {
        Some(DisplayAction::SetDetune(new_detune_index, new_detune_phase))
    } else {
        None
    };

    instrument.set_overdrive(controls.overdrive());

    [
        chord_root_action,
        degrees_action,
        solo_action,
        scale_root_action,
        scale_mode_action,
        wavetable_bank_action,
        wavetable_action,
        style_action,
        detune_action,
    ]
}

fn reconcile_pot_activity(
    controls: &mut Controls,
    instrument: &mut Instrument,
) -> [Option<DisplayAction>; 8] {
    let chord_action = if controls.chord_pot_active() {
        let chord_degrees = instrument.chord_degrees();
        Some(DisplayAction::SetChord(chord_degrees))
    } else {
        None
    };

    let wavetable_bank_action = if controls.wavetable_bank_pot_active() {
        let wavetable_bank = instrument.wavetable_bank();
        Some(DisplayAction::SetWavetableBank(wavetable_bank))
    } else {
        None
    };

    let note_action = if controls.note_pot_active() {
        let chord_root_degree = instrument.chord_root_degree();
        Some(DisplayAction::SetChordRootDegree(chord_root_degree))
    } else {
        None
    };

    let scale_root_action = if controls.scale_root_pot_active() {
        let scale_root = instrument.scale_root();
        Some(DisplayAction::SetScaleRoot(scale_root))
    } else {
        None
    };

    let scale_mode_action = if controls.scale_mode_pot_active() {
        let scale_mode = instrument.scale_mode();
        Some(DisplayAction::SetScaleMode(scale_mode))
    } else {
        None
    };

    let wavetable_action = if controls.wavetable_pot_active() {
        let wavetable = instrument.wavetable();
        Some(DisplayAction::SetWavetable(wavetable))
    } else {
        None
    };

    let style_action = if controls.style_pot_active() {
        let style = instrument.style();
        Some(DisplayAction::SetStyle(style))
    } else {
        None
    };

    let detune_action = if controls.detune_pot_active() {
        let (detune_index, detune_phase) = instrument.detune();
        Some(DisplayAction::SetDetune(detune_index, detune_phase))
    } else {
        None
    };

    [
        chord_action,
        wavetable_bank_action,
        note_action,
        scale_root_action,
        scale_mode_action,
        wavetable_action,
        style_action,
        detune_action,
    ]
}

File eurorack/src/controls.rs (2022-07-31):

#[allow(unused_imports)]
use micromath::F32Ext;

use daisy::hal;

use hal::adc::{Adc, Enabled};
use hal::pac::{ADC1, ADC2};

use achordion_lib::config::Config;
use achordion_lib::store::Parameters;

use crate::system::Button;
use crate::system::Probe;
use crate::system::{Cv1, Cv2, Cv3, Cv4, Cv5};
use crate::system::{Pot1, Pot2, Pot3, Pot4};

// V/OCT CV spans from -5.0 to 5.0 V.
const VOCT_CV_RANGE: f32 = 10.0;

pub struct ControlsConfig {
    pub adc1: Adc<ADC1, Enabled>,
    pub adc2: Adc<ADC2, Enabled>,
    pub alt_button: Button,
    pub pot_wavetable: Pot1,
    pub pot_note: Pot2,
    pub pot_detune: Pot3,
    pub pot_chord: Pot4,
    pub cv_voct: Cv1,
    pub cv_solo: Cv2,
    pub cv_wavetable: Cv3,
    pub cv_detune: Cv4,
    pub cv_chord: Cv5,
    pub cv_probe: Probe,
}

pub struct Controls {
    adc1: Adc<ADC1, Enabled>,
    adc2: Adc<ADC2, Enabled>,
    button: Button,
    pot1: Pot1,
    pot2: Pot2,
    pot3: Pot3,
    pot4: Pot4,
    cv1: Cv1,
    cv2: Cv2,
    cv3: Cv3,
    cv4: Cv4,
    cv5: Cv5,
    probe: Probe,

    parameters: Parameters,

    last_note_pot_reading: f32,
    last_wavetable_pot_reading: f32,
    last_chord_pot_reading: f32,
    last_detune_pot_reading: f32,

    note_source: NoteSource,

    calibration_target: CalibrationTarget,
    calibration_state: CalibrationState,

    configuration_state: ConfigurationState,
}

#[derive(Clone, Copy)]
enum CalibrationTarget {
    Cv1,
    Cv2,
    Cv5,
    None,
}

#[derive(Clone, Copy)]
enum CalibrationState {
    Inactive,
    Entering,
    CalibratingLow,
    CalibratingHigh(f32),
    Succeeded,
    Failed,
}

#[derive(Clone, Copy)]
enum ConfigurationState {
    Inactive,
    Active,
}

#[derive(Clone, Copy)]
enum Submenu {
    None,
    Calibration,
    Configuration,
}

impl Submenu {
    pub fn is_none(&self) -> bool {
        matches!(self, Self::None)
    }

    pub fn is_calibration(&self) -> bool {
        matches!(self, Self::Calibration)
    }

    pub fn is_configuration(&self) -> bool {
        matches!(self, Self::Configuration)
    }
}

#[derive(Clone, Copy)]
enum NoteSource {
    Cv,
    Pot,
}

impl Controls {
    pub fn new(config: ControlsConfig, parameters: Parameters) -> Self {
        let mut controls = Self {
            adc1: config.adc1,
            adc2: config.adc2,
            button: config.alt_button,
            pot1: config.pot_wavetable,
            pot2: config.pot_note,
            pot3: config.pot_detune,
            pot4: config.pot_chord,
            cv1: config.cv_voct,
            cv2: config.cv_solo,
            cv3: config.cv_wavetable,
            cv4: config.cv_detune,
            cv5: config.cv_chord,
            probe: config.cv_probe,

            parameters,

            // These values are used to cache the last read value while the pot
            // is in its alternative mode (depending on the button state).
            last_note_pot_reading: 0.0,
            last_wavetable_pot_reading: 0.0,
            last_chord_pot_reading: 0.0,
            last_detune_pot_reading: 0.0,

            note_source: NoteSource::Pot,

            calibration_target: CalibrationTarget::None,
            calibration_state: CalibrationState::Inactive,

            configuration_state: ConfigurationState::Inactive,
        };

        // Initial probe tick, so the signal has enough time to propagate to all
        // the detectors.
        controls.probe.tick();

        controls
    }

    pub fn parameters(&self) -> Parameters {
        self.parameters
    }

    pub fn note(&self) -> Option<f32> {
        if self.parameters.note < 0.5 / 12.0 {
            None
        } else {
            Some(self.parameters.note)
        }
    }

    pub fn solo(&self) -> Option<f32> {
        if self.parameters.solo_enabled {
            Some(self.parameters.solo)
        } else {
            None
        }
    }

    pub fn note_from_pot(&self) -> bool {
        matches!(self.note_source, NoteSource::Pot)
    }

    pub fn wavetable(&self) -> f32 {
        self.parameters.wavetable
    }

    pub fn chord(&self) -> f32 {
        self.parameters.chord
    }

    pub fn style(&self) -> f32 {
        self.parameters.style
    }

    pub fn detune(&self) -> f32 {
        self.parameters.detune
    }

    pub fn wavetable_bank(&self) -> f32 {
        self.parameters.bank
    }

    pub fn scale_root(&self) -> f32 {
        self.parameters.scale_root
    }

    pub fn scale_mode(&self) -> f32 {
        self.parameters.scale_mode
    }

    pub fn active(&self) -> bool {
        self.button.active() || self.pots_active()
    }

    fn pots_active(&self) -> bool {
        self.pot1.active() || self.pot2.active() || self.pot3.active() || self.pot4.active()
    }

    pub fn wavetable_bank_pot_active(&self) -> bool {
        self.button.active() && self.pot1.active()
    }

    pub fn wavetable_pot_active(&self) -> bool {
        !self.button.active() && self.pot1.active()
    }

    pub fn note_pot_active(&self) -> bool {
        !self.button.active() && self.pot2.active()
    }

    pub fn scale_root_pot_active(&self) -> bool {
        self.button.active() && self.pot2.active()
    }

    pub fn chord_pot_active(&self) -> bool {
        !self.button.active() && self.pot4.active()
    }

    pub fn style_pot_active(&self) -> bool {
        self.button.active() && self.pot4.active()
    }

    pub fn detune_pot_active(&self) -> bool {
        !self.button.active() && self.pot3.active()
    }

    pub fn scale_mode_pot_active(&self) -> bool {
        self.button.active() && self.pot3.active()
    }

    pub fn calibration_waiting_low(&self) -> bool {
        matches!(self.calibration_state, CalibrationState::Entering)
            || matches!(self.calibration_state, CalibrationState::CalibratingLow)
    }

    pub fn calibration_waiting_high(&self) -> bool {
        matches!(self.calibration_state, CalibrationState::CalibratingHigh(_))
    }

    pub fn calibration_succeeded(&self) -> bool {
        matches!(self.calibration_state, CalibrationState::Succeeded)
    }

    pub fn calibration_failed(&self) -> bool {
        matches!(self.calibration_state, CalibrationState::Failed)
    }

    pub fn config_open(&self) -> bool {
        self.active_submenu().is_configuration()
    }

    pub fn config(&self) -> Config {
        self.parameters.config
    }

    pub fn update(&mut self) {
        self.sample();
        self.reconcile();
    }

    fn sample(&mut self) {
        self.pot1.start_sampling(&mut self.adc2);
        self.pot2.start_sampling(&mut self.adc1);
        self.pot1.finish_sampling(&mut self.adc2);
        self.pot2.finish_sampling(&mut self.adc1);

        self.pot3.start_sampling(&mut self.adc2);
        self.pot4.start_sampling(&mut self.adc1);
        self.pot3.finish_sampling(&mut self.adc2);
        self.pot4.finish_sampling(&mut self.adc1);
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

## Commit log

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2021-03-27 Pin to a fork of usbd-midi
    The project is not up-to-date on crates.io. In order to make sure it
    won't disappear, creating a fork.
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2021-03-31 Implement simple oscillator following flowdsp
    This patch merely integrates code described in
    https://flowdsp.io/blog/stm32f3-02-dac-dma/ into the project. Following
    patches will switch to HAL and move part of this into dedicated functions.
    [main.rs]
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2021-03-31 Remove use of HAL and MIDI
    MIDI over USB would be useful for debugging but the complexity of its
    crates is not worth it. It also depends on community HAL that is
    unfortunately missing many features that will be needed here. Because of
    this, I'm dropping all these dependencies. HALs will be written only per
    the code used and needed in this project.
    [main.rs, mod.rs]
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2021-04-04 Use oscillator in eurorack
    [main.rs]
2021-04-04 Reset midi parser when interrupted
2021-04-05 Implement simple bandlimitation in the oscillator
    [main.rs]
2021-04-09 Fix formatting of eurorack main
    [main.rs]
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2021-04-11 Fix formatting of comments
    [main.rs]
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2021-04-15 Fix quantization base CC
    It is controlled by voct - 1.0 per octave, which reflects the range of
    values stored in CC.
    [main.rs]
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2021-04-25 Group CVs for chord, scale, table and v/oct
    [Achordion.kicad_pcb]
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2021-04-25 Switch to LM4040C10
    A10 is not available on JLCPCB.
    [Achordion.sch]
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2021-04-25 Fix disconnected routes
    [Achordion.kicad_pcb]
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2021-04-26 Move harware to its own directory
    JLCPCB does not offer the MCU this was designed for. I'm starting again,
    this time making the design modular.
    [ACHORDION_REV1_FOOTPRINT_POSITIONS.csv, Achordion.kicad_pcb, Achordion.sch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]
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2021-04-27 Add reset and boot buttons
    [core.kicad_pcb, core.sch]
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2021-05-01 Move mounting holes to fix DRC
    [core.kicad_pcb]
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2021-05-01 Switch to STM32H743VIT6
    It is twice the price of STM32F4 on JLCPCB and twice as fast.
    [core.kicad_pcb, core.sch]
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2021-05-01 Add a new PCB, based around daisy seed
    [Achordion.kicad_pcb, Achordion.sch]
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2021-05-05 Remove deprecated PCB designs
    They remain available in the history.
    [ACHORDION_REV1_FOOTPRINT_POSITIONS.csv, Achordion-bom.csv, Achordion.kicad_pcb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]
2021-05-05 Move hardware to the top level
    To much nesting is hell.
    [Achordion-bom.csv, Achordion.kicad_pcb, Achordion.sch]
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2021-05-08 Replace 7 segment display by LEDs
    It's difficult to drill rectangles.
    [Achordion.kicad_pcb, Achordion.sch]
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2021-05-08 Add CV probing
    Follow mutable instruments pattern and add a normalization probe. This
    probe will send pseudo random sequence. When this sequence is detected
    on input, we know the jack is not plugged.
    [Achordion.kicad_pcb, Achordion.sch]
2021-05-08 Mix outputs when only one jack is plugged
    Following Mutable Instrument's Rings.
    [Achordion.kicad_pcb, Achordion.sch]
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2021-05-15 Add labels to PCB
    This should help while soldering. Clean PCB is nice, looking up every
    single part in schematic not so much.
    [Achordion.kicad_pcb]
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2021-05-17 Space out jacks on PCB
    This way it should be more equally distributed.
    [Achordion.kicad_pcb]
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2021-05-18 Adjust CV ranges
    V/OCT and Tonic will be driven by V/OCT limited to a smaller range in
    the mostly positive section for increased accuracy. The rest would be -8
    to 8 volts.
    [Achordion.kicad_pcb, Achordion.sch]
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2021-05-22 Mark revision 3
    Revision 2 was already sent to be printed. Since then, pad sizes were
    changed.
    [Achordion.kicad_pcb, Achordion.sch]
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2021-06-01 Add missing parts to BOM
    [Achordion.sch]
2021-06-05 Release version 0.3.0
    * Detune sections now respond logarithmically, this allows for finer
    control in lower values.
    * Added pulse waveforms of variable width.
    * Support multiple wavetable banks.
    * Label button and probe pins on the PCB.
    * Switch to Daisy Seed, STM32H7.
    [Achordion.kicad_pcb, Achordion.sch]
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2021-06-05 Send root and chord to different channels
    This fixes a bug where we were sending root and chord to both output
    channels. Due to mixing, this caused both to end up on almost zero
    level.
    [main.rs]
2021-06-05 Fix formatting of interface
    [interface.rs]
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2021-06-06 Prevent octave offset from jumping up and down
    [interface.rs]
2021-06-06 Fix complaint about unused Result
    [main.rs]
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2021-06-06 Run DSP under the main priority
    Otherwise, CV control causes noise.
    [main.rs]
2021-06-07 Release version 0.4.0
    * Allowed control of all parameters through CV:
    - Root note, adhering to V/OCT. When connected, Note potentiometer controls
    octave offset.
    - Wavetable position. When connected, Wavetable potentiometer controls the
    offset.
    - Chord. When connected, Chord potentiometer controls the offset.
    - Detune. When connected, Detune potentiometer controls the offset.
    - Scale mode.
    - Scale root note, adhering to V/OCT.
    * Fixed the bug where root and chord went to both channels.
    * Introduced fade in when the module is powered on.
    * Fixed an issue where full detune setting would disable detune.
    [Achordion.kicad_pcb, Achordion.sch]
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2021-06-10 Release version 0.5.0
    * Allow control of wavetable bank through Wavetable pot while holding the
    button.
    * Allow control of scale root through Note pot while holding the button. This
    value will be combined with the Tonic CV in case it is connected.
    * Allow control of scale mode through Chord pot while holding the button. This
    value will be combined with the Mode CV in case it is connected.
    * Remove support for 4 degrees of chords. It draws too much resources.
    [Achordion.kicad_pcb, Achordion.sch]
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2021-07-02 Use floats for audio handling
    u16 is now kept only for wavetables in order to save space. For the
    rest, floats are used as they are the native type for both DaisySeed BSP
    and Pure Data.
    This change also fixes alignment of output signal, so it is centered
    around 0.
    [main.rs]
2021-07-02 Fix eurorack interface handling
    Commit b24fd1433bb60bfe6065af0e5d830423ac457356 introduced a bug due to
    a reveresed condition.
    [interface.rs]
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2021-07-03 Lower amplitude on eurorack
    This avoids clipping.
    [main.rs]
2021-07-05 Don't run disabled degrees
    The original caused where an oscillator was disabled by setting its
    frequency to 0 had a side effect - the oscillator kept adding DC offset,
    based on the phase it got stuck in. Due to this, the center of the
    output was moving each time the instrument was switched from chord to
    single-voice mode. This patch fixes this by adding an explicit
    enabled/disabled parameter to instrument degrees.
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2021-07-05 Release version 0.6.0
    * Added tooling supporting generation of wavetables from raw audio.
    * Lowered LPF on wavetables to make the lower end thicker.
    * Use floats for audio buffers instead of u16.
    * Remove pulse wavetable bank.
    * Add a bank compiled of FM, distorted and sampled wavetables.
    * Add a bank compiled of soft wavetables.
    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
    [Achordion.kicad_pcb, Achordion.sch]
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2021-07-10 Reset the display back to chords
    [main.rs]
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2021-07-31 Use daisy BSP from a fork
    This is a temporary solution to get a patch delivering flash memory
    driver to the project. Once all needed PRs get accepted upstream, this
    can be reverted.
    [main.rs]
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2021-08-01 Remove component labels from the silkscreen
    Prefer cleanliness. For manufacturing, print PDFs with all the
    components and their values spelled out in bigger letters - plus one can
    cross them out.
    [Achordion.kicad_pcb]
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2021-08-01 Widen tracks on the PCB
    Where possible, make them at least 0.5 mm wide.
    [Achordion.kicad_pcb]
2021-08-02 Replace DAC decoupling cap with LPF
    The design with big decoupling cap was taken from WM8731 used for
    Elements. However, with AK4556 used in Daisy Seed, it is not needed (or
    at least not a part of the datasheet), instead, use LPF for ~70 kHz.
    [Achordion.kicad_pcb, Achordion.sch]
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2021-08-06 Fix typo in a comment
    [main.rs]
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2021-08-09 Align user labels on the PCB schema
    With this, labels and outlines can be printed to help with soldering.
    [Achordion.kicad_pcb]
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2021-08-09 Replace tantalum DC decoupling caps with aluminium
    Tantalum has some bad stories connected with it. This patch replaces
    them with bigger, but much more common aluminium capacitors.
    [Achordion.kicad_pcb, Achordion.sch]
2021-08-09 Use 10uF for decoupling caps
    This value seems to be more common in stores. It should not matter if 22
    or 10 is used, so let's go with the common one.
    [Achordion.kicad_pcb, Achordion.sch]
2021-08-10 Widen one missed probe track
    [Achordion.kicad_pcb]
2021-08-10 Scale down input CV to -5 to +5 V
    This seems to be slightly more common than -8 to +8 V, it would allow
    narrower CV source to control the value from one end to the other and it
    adheres to unwritten 10 Vpp standard.
    [Achordion.kicad_pcb, Achordion.sch]
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2021-08-10 Fix release script for PCB
    Revision in kicad_pcb is rev, not Rev.
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2021-08-19 Fix release script to update PCB version label
2021-08-22 Change V/OCT inputs to scale 0.0 to 10.0 V
    With this, 10Vpp is used for both modulation and V/OCT inputs. It also
    makes it clear unidirectional, adjusts with beatstep and allows us to go
    all the way to the lowest C since it starts on whole number.
    There is no clear standard, but -5 to 5V and 0 to 10V seems more common
    than other ranges and I also like the numbers!
    [Achordion.kicad_pcb, Achordion.sch]
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2021-08-23 Temporarily disable one of the banks
    The code does not fit there. With this patch, the vocal wavetable is
    temporarily disabled. We need to figure out a way to fit it back, maybe
    by filtering it on the board and saving to the FLASH memory.
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2021-08-29 Reduce amplitude even further
    This should prevent clipping.
    [main.rs]
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2021-09-09 Fix formatting and leftovers from probe detection
    [controls.rs, cv.rs]
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2021-09-12 Gracefully handle invalid calibration input
    If the input is too close nearby, ignore it as an error, possibly a
    double click while calibrating or attempt to cancel it.
    [controls.rs]
2021-09-12 Gracefully handle reversed calibration input
    Not the preferred way, but in case someone does not get it, this is
    better than failing.
    [controls.rs]
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2021-09-12 Allow reset of all stored parameters on boot
    If the button is held down while booting, all stored parameters (alt
    values and calibration) will be erased.
    [main.rs]
2021-09-14 Fix input activity handling
    There were bugs that caused the display not to get updated when pot
    movement was too slow to be detected, seems like. With this, the display
    reacts better.
    [main.rs]
2021-09-14 Remove resolved TODO comment
    [main.rs]
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2021-09-19 Replace "root" with "solo"
    It is containing the isolated chord root or the solo output. Using solo
    to describes both of those is more fitting than root.
    [main.rs]
2021-09-19 State that 1% parts must be used around CV1,2
    These CVs are used for precise V/OCT input.
    [Achordion.sch]
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2021-09-25 Move scale mode control to pot 4
    This frees up alternative mode of pot 3 for configuration of play mode.
    [controls.rs]
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2021-09-25 Fix detune pot detection
    Now when there is an alternative attribute on the pot, button status
    must be checked.
    [controls.rs]
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2021-09-26 Revert "Make it possible to switch quantization of solo"
    This reverts commit 863a82ed0652487ba3f8300838f64234c39460dc.
    Adding quantization to the style knob makes it way too complex to
    understand the UI.
    [main.rs]
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2021-09-28 Replace lazy_static with manual intialization
    As a preparation for more controlled wavetable bank initialization,
    refactor the current code so it does not use lazy static but explicit
    initialization.
    [main.rs, mod.rs]
2021-09-30 Replace vowel bank with sin multiple+sum sequences
    [mod.rs]
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2021-10-06 Prevent pop on change of detune
    This is done by fading in/out the oscillators instead of abruptly
    switching them. This patch also simplifies the amplitude handling as it
    will be revamped in following patches.
2021-10-10 Store bandlimited wavetables as f32 sequences
    This costs twice as much memory, but helps avoiding runtime conversions
    from u16 to f32. As a result, the DSP loop gets about 10 % faster.
    [mod.rs]
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2021-10-27 Convert PCB to two stacked layers
    This completely reworked layout should be much easier to solder and also
    follows new front panel layout.
    [Achordion.kicad_pcb, Achordion.sch]
2021-10-27 Wire compatibility version into the PCB
    4 GPIO pins will be signaling version of the hardware to software. This
    will allow the software to remain backwards compatible to some degree.
    [Achordion.kicad_pcb, Achordion.sch]
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2021-12-10 Fix clippy warnings introduced with Rust 1.57
    [main.rs]
2021-12-12 Fix the calibration display
    The lower octave is now signalized by LEDs on the left, higher on the
    right.
2021-12-13 Fix scale tonic pot, so it does not wrap around
    [controls.rs]
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2021-12-14 Add mounting holes for distancing standoffs
    This will make the two PCBs less wobbly.
    [Achordion.kicad_pcb]
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2021-12-17 Change the CV range of chord to 0 to 10V
    Since chords are a discrete parameter, it makes sense to keep it
    quantized in the same way as tone input, suited for keys and sequencers.
    [Achordion.kicad_pcb, Achordion.sch]
2021-12-19 Decrease the brightness of LEDs
    Replace 365R with 1k. The original was just too bright, especially since
    the LEDs serve only as a simple on/off indicator. With the new value,
    they should not little less bright but still good enough even on sun.
    [Achordion.kicad_pcb, Achordion.sch]
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2022-02-03 Disable the solo voice when its input gets below 0
    Without this, controling the voice with sampled LFO that gets often
    below zero leads into lot of unwanted noise, especially when playing
    wavetables with rich harmonic content.
    [controls.rs]
2022-02-03 Resolve a bug where chord replaces silenced solo
    The original code did not recognize difference between unpugged solo and
    solo with CV input under 0. This is now fixed.
    [controls.rs]
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2022-02-27 Replace Daisy Seed with Daisy Patch Submodule
    While the current hardware design works well, it's productization would
    require custom (expensive) EMC tests. To overcome this, this patch
    redesigns the hardware to use the newly released Daisy Patch Sumbodule,
    which is by itself tested for CE and FCC. The only peripheral hardware
    are now passives and output mixer - these should not require any
    additional testing.
    As a part of this change, the module is now consisting of 2 boards
    instead of two, making Achordion skiff friendly.
    Passives were also changed from 0603 footprints to 0805. This should
    make hand soldering far easier while still allowing to use 0603 parts.
    Finally, due to lack of I/O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
    [Achordion.kicad_pcb, Achordion.sch]
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2022-03-19 Fix backup to start from the latest version
    [main.rs]
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2022-03-20 Fix schematic plot to work with KiCad 6
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2022-04-03 Fix backup timing
    With the sub-interval of 5 seconds, the scheduling was faulty and
    instead of 5 seconds, triggered the action immediatelly.
    Decreasing the interval to 1 second and increasing the timeout seems to
    fix the issue.
    This change was tested manually, through logging.
    [main.rs]
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2022-04-22 Fix documentation of CV ranges
    [controls.rs]
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2022-04-26 Fix contents of each TONE output
    After the change to Daisy Patch SM, the output was flipped. This fixes
    it so the root tone is again coming from TONE and the rest of the chord
    from TONE'.
    [main.rs]
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2022-04-26 Move power label
    It should not collide with a via.
    [Achordion.kicad_pcb]
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2022-07-18 Fix backing up of scale mode in modal
    [controls.rs]
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2022-07-20 Fix scaling of scale tonic CV to track 1V/oct
    [controls.rs]
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2022-11-03 Pin the project to a specific version
    Any Rust version newer than 1.63 produces firmware too big to fit into
    the flash.
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2023-09-30 Revert "Remove WEEE and CE from public repo"
    This reverts commit efba61ae0437d9b1e39a988e139de775eaaddcb0.
    [Achordion.kicad_pcb]
2023-09-30 Fix BOM
    [Achordion.kicad_pcb]
2023-10-09 Remove WEEE and CE from the board
    Don't use those logos unless I can attest that the given build is
    comptible with those directives.
    [Achordion.kicad_pcb]
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2024-11-25 Fix unquantized solo voice output
    Without this patch, 1V/oct input into an unquantized solo voice does not
    map correctly to output frequency. Instead of mapping whole CV values
    (e.g. 2.0 V) to C note, it is mapped to A.
    This patch fixes it.
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2025-04-19 Disable white key quantization by default
    It seems that most people use the module with a regular CV input, not
    with keyboards. While this quantization feature can be fun, it can make
    control using a regular CV, since some of the notes only subscribe to
    a narrow part of the 1V/oct range.
    With this patch, the default is now to snap to the closest note, leaving
    the white key quantization as an alternative firmware.
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2025-11-02 Prevent inlining to reduce firmware size
    The firmware was duplicating ~2KB of ADC HAL register configuration code
    at each of the 18 call sites (4 pots + 5 CVs, each with start/finish).
    Marking these methods as #[inline(never)] forces code sharing, reducing
    the .text section from 79,868 to 75,456 bytes (4.4KB savings).
    [cv.rs, pot.rs]
2025-11-02 Add pickup mode for primary controls
    This prevents abrupt parameter changes when releasing the button.
    Primary controls (note, wavetable, chord, detune) now use pickup mode,
    only resuming tracking after the potentiometer crosses within threshold
    of its previous position.
    [controls.rs]
2026-01-26 Revert "Add pickup mode for primary controls"
    This reverts commit f9e11310530916c7bc6734e40a8152c87b93300b.
    [controls.rs]
2026-04-24 Use better footprints
    This replaces the footprint of the power connector and the pots, making
    them easier to solder in.
    [Achordion.kicad_pcb, Achordion.kicad_sch]
2026-04-24 Increase edge clearance
    [Achordion.kicad_pcb]
2026-08-04 Fix freeze when TONE drops below the scale's lowest tonic
    Both quantizer variants could panic on tones below (or far above) the
    supported range: the center quantizer returned degree 0, which underflowed
    in the LED display reducer, and the white key quantizer unwrapped a failed
    note lookup. Since the firmware panics into a halt, the module froze until
    power cycle. Return degree 1 with the lowest tonic instead, clamp failed
    lookups octave-wise back towards the root, and clamp the degree on the
    display side as well.

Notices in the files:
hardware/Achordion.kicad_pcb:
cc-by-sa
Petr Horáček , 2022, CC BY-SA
